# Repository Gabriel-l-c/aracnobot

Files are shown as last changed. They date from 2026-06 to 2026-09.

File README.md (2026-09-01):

# 🕷️ Aracnobot - Estrutura de Tarefas

## ⚡ Eletrônica & Código Embarcado (Hardware & Firmware)
- [ ] **Esquema e Layout (KiCad)**
  - [ ] Desenhar o esquemático elétrico (reguladores de tensão e distribuição de potência).
	- [ ] testar os servos e categorizar os angulos limites (para nunca travar em 0 ou 180, o servo nao
	pode travar!!!).
	- [ ] Testar as baterias, descarga, medir o sinal de alimentação da bateria ( tem picos? ruidos?), 
	para analisar necessidade de circuitos de filtro e proteção.
	- [ ] Circuito de BMS (sistema de gerenciamento de bateria), para controle de carregamento, descarga,
	, protecao contra sobrecarga e subtensao.
  - [ ] Fazer o layout da PCB no KiCad (trilhas largas para os servos e definição das pegadas/capacitores).
  - [ ] Gerar arquivos Gerber para fabricação da placa.
  * problemas:
	O banco de baterias disponivel sao 3s2p litio (3 baterias de litio em seria com 1 em parelelo para cada em serie
ou seja, 6 celulas, 3 pares), a descarga maxima das baterias deve ficar em 1.5C ( para uam bateria de 3Ah de capacidade, 
1.5 C =  4.5A de descarga maxima), cada celula tem 4V2 de tensão maxima e 1.5Ah de descarga. Logo, nao conseguimos
alcançar a potência (carga pesada e motores travados, todos sendo usados de uma vez). Dentro disso, temos que 
montar o firmware afim de nunca ultrapassar o consumo de 4.5A total, nao usar todas as patas de uma vez, carga leve, etc.

  - [ ] Circuito do regulador dos motores. Cuidados e problemas:
  A maior parte de potencia sera consumida pelos motores, logo e onde os reguladores vão trabalhar mais e onde mais energia
  sera transformada em calor. Logo, uma pesquisa de reguladores ideias para a carga de tensão de entrada e corrente de saida
  deve ser feita para iniciar o circuito. Reguladores sugestao: K7805, XL4015.
 
- [ ] **Configuração Inicial do Código**
  - [ ] Configurar ambiente de desenvolvimento (PlatformIO, Arduino IDE ou ESP-IDF).
  - [ ] Mapear os pinos físicos da PCB criada para as definições de variáveis no código.
- [ ] **Cinemática e Movimentação junto a equipe de estrutura**
  - [ ] Implementar algoritmo de Cinemática Inversa (IK) para as pernas.
  - [ ] Desenvolver padrões de marcha (Gait Patterns: tripé, onda, etc.).
  - [ ] Criar funções de estabilização corporal integrando sensor IMU/Giroscópio.
- [ ] **Comunicação, Telemetria & Proteção**
  - [ ] Configurar protocolo sem fio (Wi-Fi, Bluetooth ou ESP-NOW) para controle remoto.
  - [ ] Criar rotina de leitura de nível de bateria e alertas de subtensão para proteger as células LiPo.

## 📐 Estrutura Mecânica Física

## 👁️ Visão Computacional & Percepção

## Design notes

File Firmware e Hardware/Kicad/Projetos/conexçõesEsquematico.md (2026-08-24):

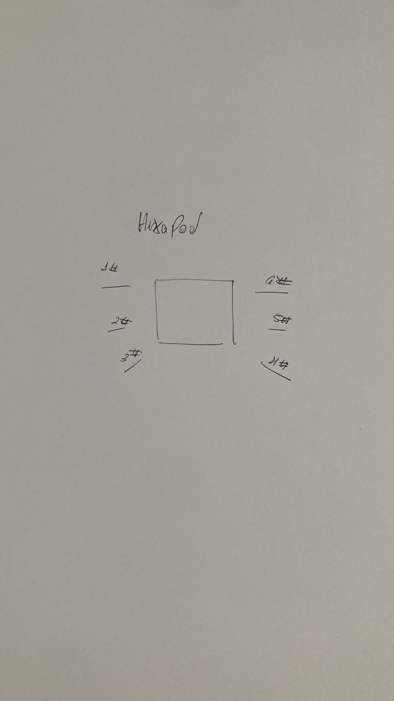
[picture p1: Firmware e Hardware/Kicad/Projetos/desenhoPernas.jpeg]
hexapod pernas


### Tabela de Conexões (Pinos de Sinal PWM)

| Perna | Articulação (Servo) | Pino ESP32 (GPIO) | Observação |
| :--- | :--- | :--- | :--- |
| **Perna 1** | Base (Coxa) | GPIO 33 | |
| | Meio (Fêmur) | GPIO 25 | |
| | Ponta (Tíbia) | GPIO 26 | |
| **Perna 2** | Base (Coxa) | GPIO 27 | |
| | Meio (Fêmur) | GPIO 14 | Pino de boot (Evitar carga pesada na inicialização)|
| | Ponta (Tíbia) | GPIO 12 | Pino de boot (Se o ESP32 não ligar, verifique este servo)|
| **Perna 3** | Base (Coxa) | GPIO 4 | |
| | Meio (Fêmur) | GPIO 32 |  |
| | Ponta (Tíbia) | GPIO 15 |Pino de boot (Emite sinal rápido ao ligar)  |
| **Perna 4** | Base (Coxa) | GPIO 5 | Pino de boot (Pode dar um pequeno tranco ao ligar)|
| | Meio (Fêmur) | GPIO 2 | LED Interno / Dá tranco no boot |
| | Ponta (Tíbia) | GPIO 35| Botão BOOT / Risco de travar o código se puxado para LOW|
| **Perna 5** | Base (Coxa) | GPIO 21 | |
| | Meio (Fêmur) | GPIO 19 | |
| | Ponta (Tíbia) | GPIO 18 | |
| **Perna 6** | Base (Coxa) | GPIO 23 | |
| | Meio (Fêmur) | GPIO 22 | |
| | Ponta (Tíbia) | GPIO 13 | |

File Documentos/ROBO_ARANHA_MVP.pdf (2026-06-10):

Projeto Robô Hexápode para Segurança Pública — MVP v5.0

## PROJETO ROBÔ HEXÁPODE PARA SEGURANÇA PÚBLICA

### MVP 12 Meses — Orçamento Enxuto

Equipe Voluntária | Foco em Componentes Essenciais
Versão: 5.0 | Junho de 2026

### SUMÁRIO

I. Introdução e Definição de MVP

II. Visão Realista

III. Cronograma Executivo (12 Meses)

IV. Divisão de Trabalho e Competências

V. Orçamento Realista

VI. Recursos Gratuitos

VII. Riscos e Mitigação

VIII. Documentação Esperada

IX. Timeline Visual

X. O que a Equipe Vai Aprender

XI. Próximas Ações

XII. Definição de Sucesso em 12 Meses

XIII. Referências de Projetos Hexápodes

### I. INTRODUÇÃO E DEFINIÇÃO DE MVP

O Projeto

O ArachnoBot é uma proposta de Veículo Terrestre Não Tripulado (UGV) com morfologia hexápode, desenvolvido por equipe voluntária com objetivo de demonstrar, em 12 meses, um protótipo funcional capaz de locomover-se em terrenos variados, identificar pessoas por meio de visão computacional e ser operado remotamente via Wi-Fi. O projeto situa-se na interseção de robótica móvel, aprendizado de máquina e sistemas embarcados, com ênfase em baixo custo e tecnologia aberta.

O que é MVP

MVP — Minimum Viable Product, ou Produto Mínimo Viável — é o menor conjunto de funcionalidades que permite validar o conceito central de um projeto com o menor desperdício possível de tempo, dinheiro e esforço. A ideia vem do desenvolvimento de software, mas se aplica diretamente a projetos de hardware e robótica: em vez de tentar construir o robô definitivo de uma vez, constrói-se a versão mais simples que ainda demonstra que o conceito funciona.

No contexto deste projeto, o MVP não é o robô ideal — é o robô mínimo que anda, enxerga e obedece. Qualquer funcionalidade além disso (navegação autônoma completa, mapeamento 3D, comunicação de longo alcance, payload de resgate) pertence a versões futuras. Essa disciplina é essencial para uma equipe voluntária com horas limitadas: sem um escopo mínimo bem definido, o projeto tende a crescer indefinidamente e nunca terminar.

O MVP deste projeto é considerado alcançado quando o robô: locomove-se de forma estável em múltiplos terrenos, transmite vídeo ao vivo para o operador, detecta pessoas com modelo de machine learning embarcado no Raspberry Pi, opera com autonomia mínima de uma hora e pode ser controlado remotamente via Wi-Fi — tudo isso dentro do orçamento de R$ 700 a R$ 920 em componentes novos e em 12 meses de trabalho.

### II. VISÃO REALISTA

Objetivo

Entregar um protótipo funcional de robô hexápode que demonstre: locomoção em terrenos variados, visão computacional com detecção de pessoas, autonomia básica e aprendizado prático em engenharia mecânica, eletrônica e machine learning.

Chassi e Estrutura

O chassi e todas as peças estruturais serão produzidos em impressora 3D Creality K1C com filamento PLA. O projeto não parte do zero: já existem modelos CAD prontos de robôs hexápodes open source como referência base, que serão adaptados conforme as especificidades da equipe. Isso elimina semanas de modelagem do zero e permite focar na integração dos sistemas.

Equipe

Voluntários entre 8 e 12 pessoas trabalhando em horas livres, sem vínculo formal. Todos os integrantes compartilham a responsabilidade de testes e documentação ao longo do projeto — não existe uma pessoa dedicada exclusivamente a essa função.

Orçamento

MVP Mínimo: R$ 700. MVP com sensores básicos: R$ 920. A equipe já possui: Raspberry Pi 4B, câmera RPi v2, bateria Li-Po 11.1V, ESP32 e filamento PLA — totalizando aproximadamente R$ 880 em componentes disponíveis.

Tempo por Pessoa

Aproximadamente 8 a 12 horas semanais por integrante, compatível com rotina de trabalho ou estudo.

### III. CRONOGRAMA EXECUTIVO (12 MESES)

T1 — Meses 1 a 3: Design e Prototipagem

- Mês 1: Adaptação do modelo CAD de referência para a K1C, definição de encaixes e tolerâncias de impressão
- Mês 2: Compra dos componentes (R$ 700), início das impressões, montagem dos servomotores MG90 na primeira perna
- Mês 3: Uma perna funcional com controle de servos validado

T2 — Meses 4 a 6: Integração e Locomoção

- Mês 4: Seis pernas montadas e controladas pelo firmware base
- Mês 5: Algoritmos de marcha (tripod gait) implementados e testados em campo
- Mês 6: Câmera integrada com stream de vídeo ao vivo, pipeline de detecção de pessoas ativo

T3 — Meses 7 a 9: Machine Learning e Autonomia

- Mês 7: Coleta do dataset (500+ imagens), treinamento inicial no Google Colab
- Mês 8: Modelo ML integrado ao Raspberry Pi, inferência em tempo real
- Mês 9: Autonomia básica funcionando — robô reage a detecção sem intervenção do operador

T4 — Meses 10 a 12: Testes, Polimento e Documentação

- Mês 10: Testes em campo com diferentes terrenos e condições de luz
- Mês 11: Correções, otimização de consumo de bateria, polimento geral
- Mês 12: Documentação final, vídeo de demonstração, relatório de lições aprendidas

### IV. DIVISÃO DE TRABALHO E COMPETÊNCIAS

A tabela abaixo apresenta as funções, quantidade de integrantes e carga horária semanal estimada. Testes e documentação são responsabilidade compartilhada de toda a equipe — não existe função dedicada para isso.

Função | Qtd | Horas/semana | Área Principal
Lead Mecânico | 1 | 10h | Engenharia Mecânica
Mecânico | 1 | 8h | Engenharia Mecânica
Lead Eletrônico | 1 | 10h | Engenharia Elétrica
Firmware Lead | 2 | 12h | Sistemas Embarcados / Integração
Firmware Dev | 1 | 8h | Sistemas Embarcados
ML Engineer | 1 | 10h | Machine Learning
Visão Computacional | 1 | 8h | Computer Vision

Tabela 1 — Composição da equipe e carga horária

Lead Mecânico

O Lead Mecânico é o responsável central pelo projeto estrutural do robô. Adapta os modelos CAD de referência para a impressora K1C, define tolerâncias de encaixe considerando as características do PLA e as dimensões dos servomotores MG90, revisa e aprova cada peça antes da impressão, decide estratégias de reforço estrutural nas regiões de maior esforço mecânico (juntas de quadril e fêmur), e resolve problemas de montagem que exijam redesenho. É o ponto final de decisão para qualquer questão de estrutura física.

Mecânico (1 pessoa)

Com modelos CAD de referência prontos e a K1C disponível, uma única pessoa de bancada é suficiente para este escopo. O Mecânico opera a K1C para impressão das peças, realiza o pós-processamento (remoção de suportes, lixamento de encaixes), monta as pernas e o chassi, aperta os parafusos nos torques corretos para não comprimir o PLA, e testa a amplitude de movimento de cada articulação antes de passar para a eletrônica. Todo problema que exija redesenho vai de volta ao Lead Mecânico.

Lead Eletrônico

O Lead Eletrônico é responsável por todo o projeto de circuito do robô: projetar o esquema elétrico completo da distribuição de energia (bateria Li-Po 11.1V → BEC 5V/3A → servos e ESP32), definir a topologia de conexão dos 18 servomotores MG90 evitando sobrecarga de corrente em qualquer ponto, projetar ou montar a PCB, escolher e validar conectores XT60 e JST, e garantir que nenhum componente opere fora da faixa segura de tensão ou corrente. É o responsável final por qualquer decisão de circuito e pela segurança elétrica do sistema.

Firmware Lead (2 pessoas)

Dada a ausência de especialistas em controle e na integração dos nós do projeto, a função é ocupada por duas pessoas com divisão interna clara. O primeiro Firmware Lead cuida da arquitetura de software embarcado e controle: define como o ESP32 gera sinais PWM para os 18 servos em paralelo sem conflito de threads, estabelece o protocolo de comunicação serial/I2C entre ESP32 e Raspberry Pi, escreve o código de controle de marcha em C (tripod gait) e integra o driver do IMU MPU6050. O segundo Firmware Lead cuida da infraestrutura de integração e DevOps: configura e mantém o servidor de CI (container Docker rodando no próprio Raspberry Pi ou em servidor externo), gerencia o repositório GitHub com branches protegidas e pipelines de CI/CD, estabelece a comunicação de telemetria Wi-Fi (protocolo, autenticação e stream de dados), e garante que os módulos de ML e visão computacional se integrem corretamente ao sistema operacional do Pi. Ambos compartilham o debugging de integração entre áreas.

Firmware Dev

O Firmware Dev implementa funcionalidades dentro da arquitetura definida pelos dois Firmware Leads — sem responsabilidade de decisão de arquitetura ou DevOps. Na prática: escreve as rotinas de PWM, o driver de comunicação I2C com o IMU MPU6050, o protocolo de recebimento de comandos via Wi-Fi e os loops de controle dos servos. A diferença central em relação aos Leads é que o Dev executa dentro das regras que os Leads estabeleceram, e reporta a eles quando encontra limitações de arquitetura que precisam ser revisadas.

ML Engineer

O ML Engineer é responsável por todo o pipeline de aprendizado de máquina: define a estratégia de coleta do dataset (ambientes, iluminação, ângulos), organiza e anota as imagens (mínimo 500), escolhe a arquitetura de rede neural mais leve para inferência no Raspberry Pi (MobileNet, YOLOv5n ou similar), treina o modelo no Google Colab com transfer learning a partir de pesos pré-treinados, exporta o modelo em formato compatível com o Pi (TensorFlow Lite ou ONNX), e retreina quando o modelo não generalizar bem para novos ambientes.

Visão Computacional

A Visão Computacional integra o modelo do ML Engineer com a câmera RPi v2 em tempo real: escreve o pipeline de captura de frames com OpenCV, passa cada frame pelo modelo de detecção e extrai bounding boxes com confiança mínima configurável, implementa tracking para manter o ID de cada pessoa detectada entre frames, transforma as saídas de detecção em sinais de controle que o firmware usa (ex.: pessoa à esquerda → virar esquerda), e otimiza o pipeline para atingir taxa mínima de 10 FPS no Pi sem travar o sistema.

Testes e Documentação — Responsabilidade Compartilhada

Não existe uma pessoa dedicada a testes e documentação. Cada integrante documenta o que produz: o Lead Mecânico entrega os arquivos STL e CAD final; o Lead Eletrônico entrega o esquema elétrico e BOM com links; os Firmware Leads mantêm o README técnico e o histórico do repositório GitHub; o ML Engineer documenta o processo de treinamento e métricas; e a Visão Computacional registra os parâmetros do pipeline. Nos meses 10 a 12 toda a equipe contribui para o vídeo final, o relatório de lições aprendidas e o guia de montagem.

### V. ORÇAMENTO REALISTA

Opção 1: MVP Mínimo — R$ 700

Item | Qtd | R$
Servomotores MG90 | 18 | 324
Alumínio (barras 20x20, 1m total) | — | 120
Parafusos, porcas, rolamentos (kit) | — | 100
Fios, conectores, garras servo | — | 80
PCB (perftape ou fenolite) | — | 40
BEC 5V/3A | — | 30
Conectores XT60, JST (kit) | — | 6
TOTAL | — | 700

Tabela 2 — Componentes MVP mínimo

Opção 2: MVP com Sensores Básicos — R$ 920

Item | Qtd | R$
Opção 1 (base) | — | 700
Sensor Ultrassom HC-SR04 | 4 | 120
IMU MPU6050 | 1 | 40
Extras (LEDs, buzzer, fita) | — | 60
TOTAL | — | 920

Tabela 3 — Componentes MVP com sensores

Componentes Já Disponíveis na Equipe

Item | Valor estimado (R$)
Raspberry Pi 4B | 350
Câmera RPi v2 | 150

Item | Valor estimado (R$)
Bateria Li-Po 11.1V | 150
ESP32 | 80
Filamento PLA (K1C) | 150
Impressora K1C | já disponível
SUBTOTAL disponível | ~R$ 880

Tabela 4 — Componentes disponíveis

Total geral do projeto considerando componentes novos mais os já disponíveis: entre R$ 1.580 e R$ 1.800.

### VI. RECURSOS GRATUITOS

Recurso | Plataforma | Custo
CAD | Fusion 360 (licença educação) | Grátis
Impressão 3D | K1C (já disponível) | Grátis
GPU para ML | Google Colab | Grátis (15h/mês)
Repositório e CI | GitHub + GitHub Actions | Grátis
Containers | Docker (no próprio Pi) | Grátis
Comunicação | Discord / Telegram | Grátis
Documentação | Google Docs / Notion | Grátis
Dev Tools | VS Code, Python, TensorFlow | Grátis (open source)

Tabela 5 — Recursos disponíveis sem custo

### VII. RISCOS E MITIGAÇÃO

Servo MG90 fraco

Testar 2 a 3 unidades antes de comprar as 18. Se insuficiente, usar redução mecânica impressa em PLA ou migrar para MG996R no eixo de quadril.

Peça impressa quebrando

Imprimir com 40% de preenchimento mínimo e pelo menos 3 paredes. Manter STLs versionados no GitHub para reimprimir qualquer peça rapidamente.

Cinemática não convergindo

Testar primeiro em simulação (CAD animado). Se não funcionar, usar 2 graus de liberdade por perna no lugar de 3.

Bateria descarregando rápido

Normal com 18 servos em carga. Objetivo de autonomia: 1 a 2 horas. Monitorar consumo com medidor de corrente e identificar servos que travam.

ML não generalizando

Coletar mais dados com variação de iluminação e ângulo. Retreinar no Colab. Usar data augmentation para ampliar o dataset sem coletar mais imagens.

Integração entre módulos falhando

Os dois Firmware Leads são responsáveis por integração. Estabelecer interfaces definidas entre módulos antes de começar — ninguém começa sem documentar a interface que vai exportar.

Docker ou servidor de CI caindo

O Raspberry Pi do próprio robô pode hospedar o servidor de integração em container. Se o Pi estiver em campo, usar GitHub Actions como fallback de CI.

Equipe desistindo

Equipe de 8 pessoas reduz o risco de paralisia por saída de um integrante. Documentação clara no GitHub garante que o substituto consiga continuar sem depender de transferência de conhecimento verbal.

Demora no AliExpress

Comprar os componentes 1 a 2 meses antes do início da montagem. Peças pequenas (parafusos, conectores) comprar em loja local como backup.

### VIII. DOCUMENTAÇÃO ESPERADA (MÊS 12)

### 1. Robô Funcional

- Protótipo v1.0 construído, testado e demonstrável publicamente
- Anda em múltiplos terrenos (concreto, grama, terreno irregular leve)
- Detecta pessoas com ML em tempo real
- Autonomia mínima de 1 hora

### 2. Código Fonte (GitHub)

- Firmware em Python e C, mínimo 3.000 linhas de código
- Modelos ML exportados em TensorFlow Lite ou ONNX
- Dataset anotado com mínimo de 500 imagens
- README claro com instruções de build, flash e operação
- Dockerfile para o ambiente de integração

### 3. Documentação Técnica

- Guia de montagem passo a passo com fotos
- Arquivos CAD (Fusion 360) e STLs prontos para impressão na K1C
- Bill of Materials (BOM) com links e preços atualizados
- Esquema elétrico completo
- Guia de operação do robô

### 4. Mídia

- Vídeos de testes em campo
- Vídeo final de demonstração (3 a 5 minutos)
- Fotos do processo de construção
- Slides para apresentação

### 5. Relatório Final

- O que funcionou e por quê
- O que não funcionou e por quê
- Lições aprendidas por área
- Roadmap para a versão 2.0

### IX. TIMELINE VISUAL

Período | Marcos
Meses 1–3 | CAD adaptado | Componentes comprados | 1 perna funcional
Meses 4–6 | 6 pernas montadas | Algoritmos de marcha | Câmera + detecção
Meses 7–9 | Dataset + treinamento | ML no robô | Autonomia básica
Meses 10–12 | Testes em campo | Polimento | Documentação final

Tabela 6 — Timeline executivo

### X. O QUE A EQUIPE VAI APRENDER

Área | Conteúdo
Mecânica | Cinemática, dinâmica de hexápodes, impressão 3D com K1C, tolerâncias de PLA
Eletrônica | PCB design, distribuição de potência, seleção de componentes
Firmware | C embarcado, PWM, I2C, threads, protocolos de comunicação serial e Wi-Fi
Integração / DevOps | Docker, GitHub Actions, CI/CD, integração hardware-software, debugging de sistema
Machine Learning | Transfer learning, dataset curation, treinamento no Colab, exportação de modelos
Visão Computacional | OpenCV, CNN, detecção de objetos, tracking, pipeline em tempo real

Tabela 7 — Aprendizados por área

### XI. PRÓXIMAS AÇÕES

Esta semana

- Reunir a equipe e confirmar os integrantes de cada função
- Definir responsabilidades individuais e os dois Firmware Leads
- Montar cronograma compartilhado no GitHub Projects ou Notion
- Pesquisar e selecionar o modelo CAD de referência para adaptação

Próximas 2 semanas

- Iniciar adaptação do CAD no Fusion 360
- Fechar lista de compra (BOM) e realizar o pedido dos componentes
- Criar o repositório GitHub com estrutura de branches, README inicial e Dockerfile base
- Configurar o ambiente Docker no Raspberry Pi

Mês 1

- CAD da primeira perna finalizado e aprovado pelo Lead Mecânico
- Componentes recebidos e conferidos
- Primeira perna impressa na K1C e montada

### XII. DEFINIÇÃO DE SUCESSO EM 12 MESES

O projeto será considerado bem-sucedido quando entregar um protótipo funcional que atenda aos seguintes critérios:

- Anda em múltiplos terrenos de forma estável
- Transmite vídeo ao vivo para o operador
- Detecta pessoas com ML embarcado no Raspberry Pi
- Opera com autonomia mínima de 1 hora
- Pode ser controlado remotamente via Wi-Fi
- Está completamente documentado no GitHub
- Pronto para demonstração pública
- Serve como base sólida para a versão 2.0

Custo em componentes novos: R$ 700 a R$ 920

Tempo total: 12 meses com 8 a 12 horas semanais por pessoa

Equipe: 8 voluntários

Impacto: portfólio técnico relevante para currículo e GitHub de todos os integrantes

### XIII. REFERÊNCIAS DE PROJETOS HEXÁPODES

Os repositórios abaixo servem como referência de arquitetura, código e documentação. Os modelos CAD e algoritmos devem ser adaptados e não copiados diretamente. Dar crédito quando utilizar código ou estruturas de terceiros.

Repositório | Relevância
mithi/hexapod | Cinemática inversa e simulação visual — base matemática do movimento
MakeYourPet/hexapod | Design mecânico acessível e controle de servos — referência de montagem
rookidroid/hexapod | Implementação embarcada de baixo custo — referência de firmware
SmallpTsai/7688-hexapod | Integração com IoT e comunicação Wi-Fi — referência de telemetria
neuroprod/InsectRobotSimulatio n | Simulação de locomoção bioinspirada — validação de algoritmos
ByteRyze/Hexapod_2 | Referência de hardware e estrutura física — tolerâncias e encaixes
ClimbSnail/HexapodRobot_STC 15 | Firmware em microcontrolador de baixo custo — referência de C embarcado
JakobLeander/hexapod | Planejamento de trajetória e controle de marcha — algoritmos de gait

Tabela 8 — Repositórios de referência

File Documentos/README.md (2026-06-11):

# ArachnoBot — Proposta de UGV para Suporte em Ambientes Hostis e Primeiros Socorros

> *"Os cientistas estudam o mundo como ele é; os engenheiros criam o mundo que nunca existiu."*
> — Theodore von Kármán

---

## Sobre o Projeto

O **ArachnoBot** é uma proposta de **Veículo Terrestre Não Tripulado (UGV)** com morfologia hexápode. 

Ele foi pensado a partir do cenário de uso atual de drones pela polícia da Grande Vitória. Com isso, uma ideia veio à mente: quais limitações os drones deles têm e como seria possível suprir essas limitações? 

Como a parte de ações policiais possui conflitos éticos e de violência, optou-se pela área de primeiros socorros, que tem o mesmo apelo de necessidade de tecnologia, porém ainda não conta, por exemplo, com drones dedicados a isso. 

Logo, ele foi concebido para atuar como ferramenta de apoio em operações de primeiros socorros, especialmente em locais onde a presença humana direta representa risco severo ou é temporariamente inviável.

O projeto se situa na interseção de três domínios:

- **Robótica Móvel de Resgate** — navegação e teleoperação em terrenos adversos
- **Atendimento Pré-Hospitalar (APH)** — entrega de suprimentos médicos essenciais a vítimas isoladas
- **Engenharia de Sistemas Embarcados** — plataforma de baixo custo e arquitetura aberta

### Areas Que São Trabalhadas :

* **Sistemas Embarcados:** Programação e arquitetura de computação embarcada de tempo real (utilizando microcontroladores e microprocessadores). Foca-se no desenvolvimento do firmware de controlo central, gestão de interrupções, temporização e geração de sinais PWM (Pulse Width Modulation) coordenados para o acionamento síncrono dos 18 servomotores do robô.
* **Redes de Comunicação e IoT:** Implementação de arquiteturas de rede sem fios (Wi-Fi e Radiofrequência) de baixa latência e alta resiliência para teleoperação em ambientes confinados. Inclui a especificação de protocolos de comunicação leves (como MQTT para telemetria estruturada e fluxos UDP) destinados ao envio de dados de sensores e à transmissão contínua (*streaming*) de vídeo em tempo real.
* **Robótica Móvel e Cinemática:** Estudo de modelos matemáticos de cinemática inversa aplicados a geometrias bioinspiradas, planeamento de trajetórias de marcha (gait planning) para terrenos irregulares, e controlo em malha fechada utilizando dados de giroscópios e acelerómetros para a estabilização postural.
* **Visão Computacional e Inteligência Artificial:** Integração de algoritmos de processamento digital de imagem e modelos otimizados de redes neuronais artificiais para a deteção automatizada de pessoas. O foco está na identificação de vítimas em cenários de visibilidade degradada por fumo, poeira ou baixa luminosidade.
* **Eletrónica de Potência e Gestão Energética:** Desenho de circuitos de filtragem de ruído eletromagnético provocado pelos motores, dimensionamento de sistemas de regulação de tensão de alta corrente (circuitos BEC) e monitorização inteligente do ciclo de descarga das baterias para garantir a integridade dos componentes lógicos e de processamento.

### Objetivos :
* Movimentaçaõ: robo que consiga se locomover de forma "limpa", e se adaptar a perda de 1 perna caso algum motor quebre, simulacao em 3d do robo para apurar resultado e obter dados
* Energia: Autonomia de 30min a 1h, placa personalizada  
* Visão: identificacao de obstaculos, pessoas, tudo que envolva acidente etc.
* Machine learning: algorithmo para auxiliar quem ira pilotar o robo a tomar decisoes voltadas a primeiros socorros
* Firware : estrutura de sensores e comunicação com microcontrolador eficiente.

> Este repositório documenta a **proposta, fundamentação teórica e planejamento** do projeto. O desenvolvimento do protótipo físico está em fase de iniciação.
> Apartir daqui e mais teórico : )

---

## O Problema: A Lacuna na Hora de Ouro

Em operações de Busca e Salvamento (SAR — *Search and Rescue*) e em intervenções em desastres — incêndios urbanos, colapsos estruturais, ocorrências de segurança pública — existe uma janela temporal crítica denominada **"hora de ouro do trauma"**. Neste intervalo, intervenções simples de primeiros socorros como controle de hemorragia, abertura de vias aéreas e prevenção de hipotermia são determinantes para a sobrevivência.

As equipes de resgate humano são frequentemente **impedidas de acessar as vítimas** neste período por fatores como:

| Barreira | Exemplos |
|---|---|
| Instabilidade estrutural | Edifícios colapsados, escombros |
| Altas temperaturas | Incêndios urbanos, focos industriais |
| Zonas de exclusão tática | Protocolos de segurança em operações policiais e de defesa civil |
| Topografia adversa | Morros, becos, escadarias, regiões alagadas |

> *"Mais de 50% dos civis feridos durante combates em centros urbanos precisam apenas receber os primeiros socorros — acrescidos de um simples antibiótico oral e um analgésico. Eles precisam apenas de cuidados imediatos e de um tratamento complementar de estabilização, e não ser hospitalizados."*
> — CICV, *Primeiros Socorros em Conflitos Armados e Outras Situações de Violência*, 2006 (ICRC 007/0870)

O ArachnoBot propõe-se a preencher esta lacuna logística e temporal, projetando a capacidade de assistência do socorrista para dentro das zonas de exclusão antes ou durante o acesso humano.

---

## Objetivos

### Geral

Desenvolver a proposta e, futuramente, um protótipo funcional de UGV hexápode voltado para **reconhecimento de terreno** e **entrega remota de suprimentos de primeiros socorros** em ambientes de difícil ou impossível acesso humano imediato.

### Específicos

- Definir os requisitos mecânicos de uma plataforma hexápode capaz de transpor obstáculos urbanos típicos (escombros, degraus, terrenos irregulares)
- Especificar a arquitetura de sensoriamento e telemetria (câmera, temperatura, IMU) para transmissão de dados em tempo real ao operador
- Projetar um compartimento de carga adaptado ao transporte de suprimentos essenciais de APH
- Elaborar a arquitetura de software para teleoperação e, em estágios futuros, navegação semiautônoma
- Mapear protocolos de uso alinhados às diretrizes internacionais do CICV para primeiros socorros em ambientes hostis
- Validar a proposta com foco em baixo custo de produção e potencial de escalabilidade

---

## Fundamentação Teórica e Estado da Arte

### Robótica Autônoma em Suporte a Bombeiros

A inserção de UGVs para suporte a bombeiros em ambientes fechados já é uma realidade validada pela literatura. **Talavera et al. (2023)** demonstraram, no *Journal of Field Robotics*, a eficácia de arquiteturas autônomas para auxiliar intervenções em locais com risco de colapso estrutural — realizando reconhecimento térmico e visual que os Equipamentos de Proteção Individual (EPIs) humanos não toleram por tempo suficiente. O estudo sustenta diretamente a premissa central deste projeto: robôs terrestres podem ser a vanguarda segura de uma operação de resgate.

### Consciência Situacional e Mapeamento em Catástrofes

Em situações de desastre, a telemetria é vital. O consórcio europeu **TRADR** demonstrou que drones terrestres com sensores a laser geram mapeamento 3D de zonas sinistradas em tempo real, fornecendo aos comandantes dados críticos antes de expor as equipes ao perigo. Esta capacidade de observar sem estar presente é um dos pilares funcionais do ArachnoBot.

### APH Tático e Entrega Logística de Resgate

O desenvolvimento de robôs focados especificamente no transporte logístico de emergência — como os documentados no projeto **FireBot** (capaz de suportar temperaturas acima de 530°C, conforme CNN Portugal) — evidencia a demanda global por sistemas mecânicos de entrega em zonas hostis. O ArachnoBot incorpora este conceito adaptado ao contexto do APH: o robô não trata a vítima, mas **entrega os meios para que ela possa receber ou aplicar os primeiros socorros** sob orientação remota de um profissional.

### Protocolos Humanitários e APH em Campo

O CICV, no manual *Primeiros Socorros em Conflitos Armados e Outras Situações de Violência* (ICRC 007/0870, 2006), estabelece que a abordagem primária de uma vítima segue a sequência **A-B-C-D-E** — Vias aéreas, Respiração, Circulação, Incapacidade e Exposição. Os suprimentos transportados pelo ArachnoBot são selecionados para atender exatamente estas etapas críticas, com ênfase no controle de hemorragia (C) e na proteção contra hipotermia (E).

O **Manual de Medidas de Segurança e Primeiros Socorros** (Chang, 2015) complementa esta base com a especificação dos materiais essenciais de uma caixa de primeiros socorros de campo e os procedimentos de atendimento inicial, sendo referência direta para a definição da carga útil do robô.

### Morfologia Hexápode para Terrenos Adversos

A escolha de seis pernas é funcional, não estética. Plataformas hexápodes apresentam **redundância de locomoção** — a falha de uma perna não paralisa o sistema —, maior estabilidade estática em terrenos irregulares e capacidade de transpor obstáculos que inviabilizam plataformas rodadas. A comunidade open-source já documentou extensamente soluções de referência que fundamentarão a arquitetura mecânica deste projeto.

---

## Conceito de Operação

```
  OPERADOR / SOCORRISTA
  (zona segura)
        |
        |  Teleoperação via Wi-Fi / RF
        |  Vídeo ao vivo + telemetria
        v
  +-------------------------+
  |      ARACHNOBOT UGV     |
  |  Câmera FPV             |
  |  Sensores de telemetria |
  |  Compartimento de carga |
  |  6 pernas / servomotores|
  +-------------------------+
        |
        |  Navega pelo ambiente hostil
        v
  +-------------------------+
  |      VITIMA ISOLADA     |
  |  Recebe suprimentos     |
  |  Orientada remotamente  |
  |  pelo socorrista        |
  +-------------------------+
```

O operador, em segurança, visualiza o ambiente por meio da câmera do robô, navega até a vítima e libera os suprimentos de APH. Se a vítima estiver consciente, o socorrista pode orientá-la, ou alguém próximo,  remotamente por áudio sobre como aplicar torniquete, curativo compressivo ou cobertor térmico — seguindo os protocolos A-B-C-D-E do CICV — até a chegada da equipe de resgate ao local.

---

## Carga Útil Prevista — Kit de APH

Os suprimentos são selecionados com base nas intervenções de maior impacto na hora de ouro, conforme os protocolos do CICV (2006) e do Manual Chang (2015):

| Suprimento | Finalidade | Referência |
|---|---|---|
| Torniquete (CAT ou improviso) | Controle de hemorragia em membros | CICV Sec. 6.1.3 / Chang 14.1 |
| Bandagem de compressão | Curativo compressivo em ferimentos | CICV Sec. 6.2.6 / Chang 14.1 |
| Máscara de ressuscitação | Ventilação artificial boca-a-máscara | CICV Sec. 6.1.2 / Chang 4.2.1 |
| Curativos estéreis (P/M/G) | Cobertura de ferimentos abertos | Chang 2.2 / CICV Sec. 6.2.6 |
| Gaze + agente hemostático | Controle de sangramento profuso | CICV Sec. 6.1.3 / Chang 14.1 |
| Soro fisiológico (sachê) | Limpeza de ferimentos | Chang 2.2 e 3.3.1 |
| Cobertor térmico aluminizado | Prevenção de hipotermia e choque | CICV Sec. 6.1.5 / Chang 10 |

**Nota operacional:** O robô realiza exclusivamente a entrega de suprimentos e a transmissão de vídeo e áudio. A administração dos primeiros socorros é responsabilidade da vítima consciente orientada remotamente, ou das equipes que chegam subsequentemente.

---

## Roadmap

| Fase | Descrição | Status |
|---|---|---|
| Fase 0 | Proposta conceitual e levantamento bibliográfico | Em andamento |
| Fase 1 | Especificação de requisitos e seleção de componentes |Não iniciado |
| Fase 2 | Projeto mecânico (CAD) e simulação de cinemática | Não iniciado |
| Fase 3 | Prototipagem da plataforma de locomoção | Não iniciado  |
| Fase 4 | Integração de sensores e sistema de comunicação | Não iniciado  |
| Fase 5 | Desenvolvimento da interface de teleoperação | Não iniciado  |
| Fase 6 | Testes integrados e validação do protótipo | Não iniciado  |

---

## Repositórios de Referência — Plataformas Hexápode Open Source

| Repositório | Relevância |
|---|---|
| [mithi/hexapod](https://github.com/mithi/hexapod) | Cinemática inversa e simulação visual |
| [MakeYourPet/hexapod](https://github.com/MakeYourPet/hexapod) | Design mecânico acessível e controle de servos |
| [rookidroid/hexapod](https://github.com/rookidroid/hexapod) | Implementação embarcada de baixo custo |
| [SmallpTsai/7688-hexapod](https://github.com/SmallpTsai/7688-hexapod) | Integração com plataformas IoT e comunicação |
| [neuroprod/InsectRobotSimulation](https://github.com/neuroprod/InsectRobotSimulation) | Simulação de locomoção bioinspirada |
| [ByteRyze/Hexapod_2](https://github.com/ByteRyze/Hexapod_2) | Referência de hardware e estrutura física |
| [ClimbSnail/HexapodRobot_STC15](https://github.com/ClimbSnail/HexapodRobot_STC15) | Firmware em microcontrolador de baixo custo |
| [JakobLeander/hexapod](https://github.com/JakobLeander/hexapod) | Planejamento de trajetória e controle de marcha |

---

## Referências Bibliográficas e Documentais

CHANG, Yen-Li Chain. **Manual de Medidas de Segurança e Procedimento de Primeiros Socorros no Acampamento Escoteiro**. Projeto da Insígnia de Madeira — Curso Avançado Ramo Escoteiro, GENSM 49-PR. 2015.

CNN PORTUGAL. **Estudantes constroem robot que consegue aguentar temperaturas acima dos 530 graus**. Projeto FireBot. [S. l.], [s. d.].

COMITÊ INTERNACIONAL DA CRUZ VERMELHA (CICV). **Primeiros Socorros em Conflitos Armados e Outras Situações de Violência**. n. ICRC 007/0870. Genebra, Suíça: CICV, 2006.

DESENVOLVIMENTO de Robôs de Resgate. *Documentação Técnica de Referência.* [S. l.: s. n., s. d.].

EURONEWS. **Os robôs que ajudam os bombeiros italianos**. Projeto TRADR — Consórcio Europeu de Robótica de Resgate. [S. l.], [s. d.].

PEOPLE.CN. **Inovações em Robôs de Resgate e Transporte de Emergência**. [S. l.], [s. d.].

SAFE Search and Rescue Operations Based on Autonomous Robots: A Systematic Review of the General System Architecture. *Revisão Sistemática de Literatura em Robótica SAR.* [S. l.: s. n., s. d.].

TALAVERA et al. An autonomous ground robot to support firefighters interventions in indoor environments. **Journal of Field Robotics**, 2023.

---

## Contexto Acadêmico

Este projeto é concebido no âmbito universitário com caráter multidisciplinar, reunindo as seguintes áreas:

- **Engenharia Mecânica** — Projeto estrutural e cinemática da plataforma hexápode
- **Engenharia Elétrica / Eletrônica** — Sistemas embarcados, sensoriamento e gerenciamento de energia
- **Ciência da Computação** — Comunicação, visão computacional e interface de controle
- **Saúde / APH** — Definição dos protocolos de primeiros socorros e especificação da carga útil

---

*"Prestar os primeiros socorros não significa somente fazer respiração artificial ou colocar um curativo num ferimento. Significa também pegar na mão de alguém que está ferido, tranquilizar os que estão assustados ou em pânico, dar um pouco de si."*
— CICV, 2006

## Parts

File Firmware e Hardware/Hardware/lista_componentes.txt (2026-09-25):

Reguladores:

L7805  - 10x

Rasberrypi:
4 model b
3 model b+

Esp:

Esp32devkit u-v4
Esp32 dev kit v1
nanoEsp32-c6 v1.0 v1711

Mosfet :
IRFZ44N - 10x

Diodo:
zener:
3V0, 3V3, 3V6, 4V7, 5V1, 5V6, 6V2, 10V, 12V, 13V, 15V, 18V, 27V, 30V

BMS:
2s 15w 1,5A  - v1342
2s 10A - v813

Switch: 
SS12D00
KCD1
Connector:
deans tipo t
jst-rcy

baterias: 
3 packs de 2P - 3V7 4000mAh

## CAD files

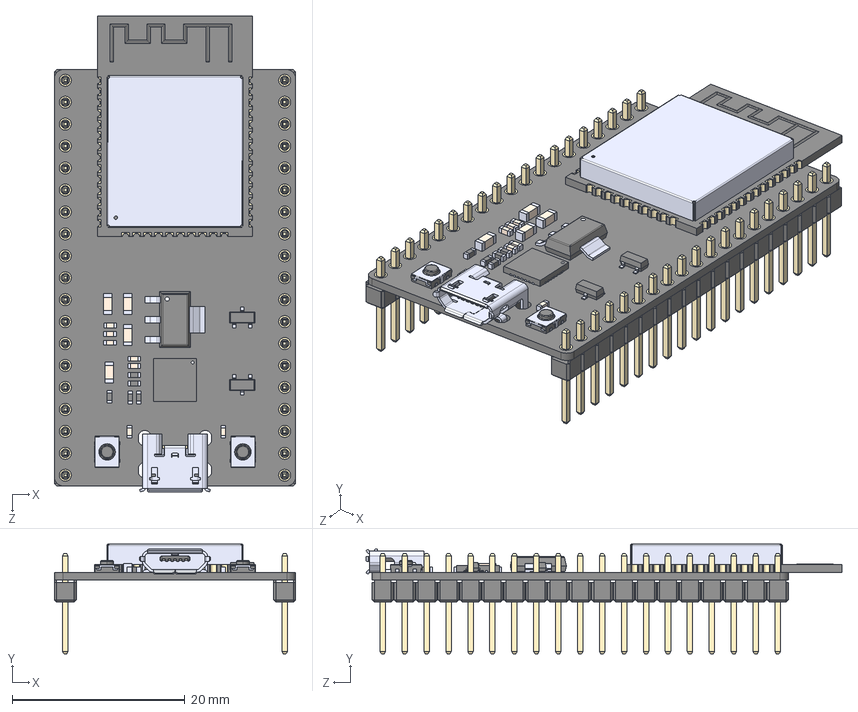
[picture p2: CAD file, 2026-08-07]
Firmware e Hardware/Kicad/Biblioteca/DEVKIT_V1_ESP32-WROOM-32/DEVKIT_V1_ESP32-WROOM-32.step
27.9 x 12.7 x 55.1 mm
board
header x 2
ESP32-WROOM-32D
micro usb
button x 2
CP2102N-A01-GQFN28
AMS1117-3.3
SS8050-G
components^DEVKIT V1 ESP32-WROOM-32

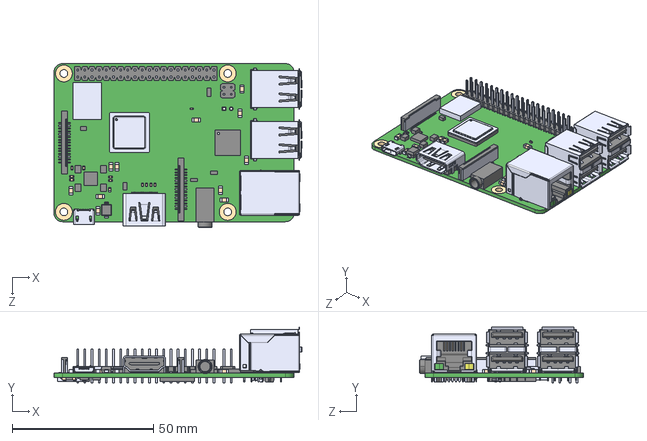
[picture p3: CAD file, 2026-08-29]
Firmware e Hardware/Kicad/Biblioteca/RASPBERRY_PI_3_MODEL_B_/RASPBERRY_PI_3_MODEL_B_.step
87.8 x 19.8 x 58.0 mm

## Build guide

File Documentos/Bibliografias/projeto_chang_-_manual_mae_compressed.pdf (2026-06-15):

PROJETO DA INSÍGNIA DE MADEIRA

## MANUAL DE MEDIDAS DE SEGURANÇA E

## PROCEDIMENTO DE PRIMEIROS SOCORROS

## NO ACAMPAMENTO ESCOTEIRO

PROJETO DE CONCLUSÃO DO CURSO AVANÇADO RAMO ESCOTEIRO 2015

CHANG YEN-LI CHAIN

CHEFE TROPA III DO GENSM - 49-PR

SUMÁRIO:

3.3. Avaliação Secundária (cuidado de ferimentos, fraturas e preparo para remoção) .....20

PREFÁCIO

Sou pediatra de formação e entrei no movimento escoteiro por causa dos meus 3 filhos, que foram escoteiros do Grupo Escoteiro Nossa Senhora Medianeira (GENSM 49-PR), há 24 anos atrás. Comecei primeira como mãe de apoio, depois como médica voluntária, e há mais de 10 anos sou chefe assistente na Tropa escoteira, e atualmente chefe da tropa III. Já participei de 3 Jamborees Internacionais (da Inglaterra, da Suécia e do Japão), 5 Jamborees Nacionais, 2 Jamborees Pan-americanos (México e Equador) e 2 ARP,4 Acanjesus (acampamentos dos grupos escoteiros do colégio Jesuítas), além dos diversos acampamentos do nosso grupo escoteiro e de outros também. Maioria das vezes trabalhei como médica.

Observei que muitos atendimentos médicos poderiam ser evitados se todos seguissem as recomendações e ensinamentos propostos pela UEB. Entretanto, o movimento escoteiro tem muita rotatividade, tanto de chefes como de escoteiros, e por isso é necessário que se lembrem sempre as recomendações de medidas de segurança e treinamento de primeiros socorros.

Este manual serve para a consulta de chefes e escoteiros a fim de organizarem seus acampamentos com segurança, prevenindo desta forma acidentes, e auxiliando-os a saberem aplicar os primeiros socorros nas situações que exigem ação.

E também ajuda osescoteiros para tirar a especialidade de primeiros socorros.

Os anexos podem parecer um pouco antigos, pois na atualidade tudo pode ser tirado do SIGUE que agora é PAXTUR. Tanta atualização do desenvolvimento e progressão das jovens, ficha médica, como autorização para a atividade. Mas são lembranças que precisam de todos esses documentos e informações para ter uma atividade escoteira com segurança.

Agradecimentos:

Ao meu assessor pessoal Nelson W. Hey.Juior.

E minhas filhas: Milena e Amanda Chang Chain que tiveram paciência e disposição para correção e digitação desse manual.

CHANG YEN-LI CHAIN

### 1. PADRÃO DE ATIVIDADE ESCOTEIRA

## O sucesso do acampamento está relacionado à:

Programação + Nutrição + Saúde + Segurança.

1.1.Antes

a) Estabelecer os objetivos de desenvolvimento que se pretende alcançar.
b) Avaliar os recursos humanos.
c) Avaliar recursos materiais.
d) Planejamento.
e) Visitar o local.
f) Reconhecimento do terreno.
g) Realização de percurso.
h) Programação.
i) Transporte.
j) Autorização.

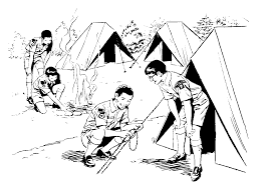
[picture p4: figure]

a) Estabelecer os objetivos.Uma atividade escoteira não é meramente uma recreação. Cada tipo de atividade enfatizará atributos das diversas áreas de desenvolvimentocomo: a aplicação de determinados conhecimentos e técnicas; a exigência de certas capacidades físicas e destrezas; e a construção e/ou consolidação de comportamentos e atitudes desejáveis. Terão os escoteiros e sua patrulha, ou tropa, aoportunidade de conviver, aprender e enfrentar desafios variados.
b) Avaliar os recursos humanos.Temos adultos qualificados na chefia para executar tal atividade? Se não temos, devemos buscar a colaboração de especialistas: do rapel, guias, mergulhadores, professores, bombeiros, etc.? Tem número suficiente de chefia? De pais de apoio? Ao estabelecer as funções, ver se a tropa está completa, e se os jovens realmente estão preparados para participar. Se os jovens são inexperientes, devemos propiciar oportunidades, ao longo das reuniões, para capacitações nas técnicas escoteiras, palestras, avaliação e treinamento, etc.
c) Avaliar recursos materiais.O nosso equipamento é apropriado e está em boas condições? As barracas estão em ordem e tem lugar para todos? Fogareiro e lamparina em ordem? Tem gás e camisinha? Verificar a arrumação da caixa de patrulha antes do acampamento. Cada patrulha deve se encarregar de completar o que faltou, além de arrumar os materiais necessários para o acampamento. Por exemplo: camisinha para o lampião, mantimentos se precisar cozinhar, considerando todas as refeições (muitas patrulhas esquecem do café da manhã do segundo dia), caixa de primeiros socorros atualizada (repor e ver data de vencimento), entre outros.

d) Planejamento. | Cabe | aos | chefes
discutirem a programação antes do acampamento: qual o tema, data, local, horário, ponto de encontro, as atividades, horário das refeições, do banho, fogo de conselho, entre outros.
e) Visitar o local.É importante a escolha e reconhecimento do local, seja qual for a atividade. Todos os detalhes devem ser
reconhecidos pela chefia para que não
haja surpresas desagradáveis. Ao planejar

a atividade e reconhecer o local deve-se levantar as hipóteses de possíveis problemas para adotar ações preventivas, e/ou preparar os meios para executar ações corretivas.
f) Reconhecimento do local. O que devemos observar durante o reconhecimento?
- Socorro médico:tenha à mão o endereço e telefone de hospitais, médicos e farmácias próximos.
- Segurança: observar a vizinhança. Procure saber se o local é frequentado, e por que tipo de pessoas; se já houve ocorrência de furtos ou atos violentos.
- Animais: se há animais ferozes e peçonhentos, etc.
- Água potável: verifique se há e qual a abundância.
- Abrigos:se há celeiros, estábulos, galpões, grutas, etc.
- Solo: verifique se o solo é permeável.Evitar acampar sobre barro.
- Transporte: verifique quais os meios de transporte existentes, e qual deles é o mais adequado para chegar no local, (transporte coletivo ou carro de apoio), os custos, horários, veículos para casos de emergência, etc.
- Comunicação: localize um telefone para contato(público ou não) considere as possibilidades e limitações do telefone celular e/ou de equipamento de rádio.
- Abastecimento: verifique se perto do local da atividade existem mercados, mercearias, etc.Isso pode simplificar a logística, no que concerne a peso, volume ou perfectibilidade dos gêneros alimentícios a transportar.
- Regulamento: costumes ou regras de cada região e/ou do local.
- Atrativos: se há represa, rios, grutas, cavernas, piscinas, locais turísticos ou históricos, fábricas, plantações que podem visitar
g) Realização de percursos. É muito importante anotar os detalhes, as distâncias, tempo gasto, pontos de apoio, ponto de referência, os níveis de dificuldade, ponto de partida e ponto de chegada. Com desenho ou mapa.
h) Programação: Cabe à chefia planejar a programação do acampamento com os horários, atividades escoteiras, refeições, horário de banho, fogo de conselho, jogo noturno, devendo ser variada e atraente.

1.2.Durante

a) Mantenha os jovens ocupados com atividades atraentes, interessantes e equilibradas (o que não é sinônimo de cansá-los nem de assoberbá-los). Um dos objetivos é a convivência, e o cansaço pode impedir a consecução de objetivos importantes. (PROGRAMAÇÃO).
b) Observar os horários de dormir. (PROGRAMAÇÃO).
c) Mantenha os jovens bem alimentados. (NUTRIÇÃO).
d) Zele pela higiene de todos, pela higiene dos locais da atividade, pela higiene na alimentação e trate de todos os ferimentos, por menor que sejam. (SAÚDE).
e) Zele pela segurança de todos no uso de ferramentas e na aplicação das atividades. (SEGURANÇA).

1.3.Depois

a) Observar se o local está mais limpo e arrumado do que antes.
b) Faça os agradecimentos aos colaboradores presentes.
c) Exija limpeza e organização de todo o material usado;
d) Faça a prestação de contas;
e) Envie cartas de agradecimento (casonecessário);
f) Avalie a atividade junto aos jovens, à Corte de Honra e à chefia.

### 2. O QUE LEVAR PARA UM ACAMPAMENTO

É importante saber o que levar e saber também o que não levar, lembrar que um escoteiro tem de ser capaz de arrumar sozinho e carregar sua própria mochila; o excesso de peso e os materiais desnecessários podem causar dor nas costas, tanto os necessários que não foram levados também pode causar problema de saúde por falta.

Todos materiais têm que ser marcados com nome e identificação da pessoa ou da patrulha e colocados dentro de sacos plásticos impermeáveis para evitarem de serem molhar quando chover.

Para a seleção dos materiais ser bem-feita devem ser considerados fatores como: clima, tipo de acampamento, localização, existência de animais peçonhentos ou insetos, tipo de atividade, alimentação, caixa de primeiro socorro e medicamentos de uso próprio, etc.

C

2.1.O que levar para um acampamento de 2 dias?

CONTEÚDO

VESTUÁRIO | EQUIPAMENTOS
1 uniforme completo | 1 mochila
3 camisetas com o motivo escoteiro | 1 saco de dormir / cobertor
2 shorts ou bermuda | 1 isolante térmico / colchonete
1 agasalho para frio | 1 lanterna com pilhas novas e um conjunto extra
1 conjunto de moletom (roupa para dormir) | 1 garrafinha de água ou cantil
2 calcinhas ou cuecas | 1 repelente
2 pares de meias | 1 protetor solar
1 tênis sobressalente | 1 capa de chuva
1 chinelo de borracha para tomar banho | 6 sacos plásticos para roupas sujas
1 boné ou chapéu | Documento pessoal, documento de convênio médico e carteira de registro da UEB
1 roupa de banho | Autorização assinada e ficha médica
| Remédio de uso contínuo (entregar para a chefia com a prescrição médica)

HIGIENE
1 toalha de banho | ACONSELHÁVEL
1 toalha de rosto | 1 cabide
1 sabonete pequeno de viagem | 4 pregadores de roupa
1 pasta dental e escova de dente | 1 máquina fotográfica
1 pente ou escova de cabelo | 1 apito
1 desodorante não aerosol | 1 bússola
1 shampoo | 1 kit de primeiros socorros (1 por patrulha)
| 1 kit de costura (1 por patrulha)
ALIMENTAÇÃO | 1 caderno e lápis/caneta
1 prato (não descartável e não quebrável) | 1 luva de proteção (para as atividades de pioneria)
1 caneca de plástico ou alumínio (não descartável e não quebrável) | 1 rolo de papel higiênico pequeno

1 colher, garfo e faca (não descartável)
1 pano de prato
* Sugestão: uma sacola de costas para
colocar todos os utensílios dentro

Todo material deve estar identificado
Tudo deve estar embalado dentro de sacos plástico impermeável

O QUE É PROIBIDO LEVAR
1. Vidros, louças ou qualquer outro tipo de material que ao quebrar possa provocar ferimentos
2. Balas, chocolates, salgadinhos ou qualquer outro tipo de "contrabando".
3. Produtos em forma de aerosol tipo repelente, protetor solar, desodorante.
4. Medicação sem prescrição médica, a Chefia não irá oferecer nenhum tipo de remédio.
5. Celular, mini games, brinquedos, rádios, bugigangas.

2.2.A Caixa de Primeiros Socorros

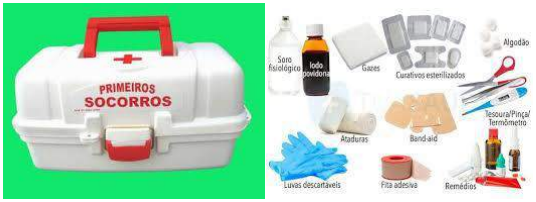
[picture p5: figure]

São várias as sugestões sobre o que contém dentro da caixa de primeiros socorros, os básicos são para curativos; os medicamentos somente são dados pela pessoa qualificada, é importante que contenha ficha médica atualizada de cada elemento, principalmente quem tem alergia a alguma coisa, e avisar a chefia o que usa no momento do acampamento, com receita, e: antibiótico. Deve trazer para acampamento quem usa medicamento de uso contínuo.ex: aerosol para asma.

Importante:

✓ Verificar a validade dos medicamentos antes de cada atividade
✓ Repor materiais do kit de primeiros socorros após cada atividade
✓ Dispor da ficha medica atualizada de cada escoteiro (durante acampamentos manter um histórico do uso de medicamentos, principalmente aqueles que necessitam de receita medica, ex. antibióticos)

Materiais:

* Atadura de crepom de tamanho pequeno e grande.
* Curativos esterilizados de 3 tamanhos: pequeno, médio e grande.
*Gazes 3 pacotes pequenos, e algodão
*Bandagem triangular (1,5m de base e 90 cm de lados) para fazer tipoia ou cobri lesão. * Esparadrapo e ou fita adesiva (micro pólen)
*Soro fisiológico 1 frasco e 5 bastonetes de soro fisiológico.
* Antisséptico em spray 1 frasco e ou 1 frasco de iodopovidona.
*band-aid 1 cx e 1 cx de cotonete.
*Luvas descartáveis.
* Álcool 70% 1 frasco pequeno.
*Sabonete antisséptico
*Termômetro,
* tesoura sem pontas.
* agulha de seringa, ou 1 pinça (paratirar fiapo)
*Amônia e vinagre (atividade no mato e no mar)
*Pomada antialérgico para picada de inseto, para contusão muscular, creme hidratante.

2.3.Telefones Importantes e Serviço de Apoio

É importante que cada patrulha tenha uma lista de telefone contendo: o contato dos chefes que acompanham a atividade externa, dos elementos e respectivos familiares (que consta na ficha de autorização), da Diretoria do grupo escoteiro, além do telefone de hospitais ou posto de saúde próximos do acampamento. Quem tem plano de saúde é bom ter a carteirinha e saber onde levar caso aconteça um acidente.

Hospital Universitário Evangélico de Curitiba Alameda Augusto Stellfeld, 1908
Fone: (41) 3240-5000

Hospital Universitário Cajurú
Av. São José, 300
Fone: (41) 3271-3000

Hospital Trabalhador,
Av.Republica Argentina 4406 Fone: (41) 3212-5700

### 3. ATENDIMENTO INICIAL À VÍTIMA DE TRAUMA

O atendimento inicial à vítima de trauma é composto por três etapas: 1ª Controle da cena, 2ª Avaliação primária e 3ª Avaliação secundária.

3.1.Controle da Cena

Controle a cena do acidente significa garantir a segurança no local e analisar o mecanismo de trauma.
Segurança no local: Antes de iniciar o atendimento à vítima, garantir a própria condição de segurança, a da vítima e a dos demais presentes. De forma alguma se exponha ao risco. Solicite ajuda especializada. Pode ser necessário isolar a área, sinalizar, acionar serviços de apoio.

3.2.Avaliação Primária

Avaliação primária serve para identificar situações de ameaça à vida e manejar de imediato a vítima. É feita sem mobilizá-la da posição inicial, salvo em condições especiais como: risco de explosão, incêndio, afogamento, desabamento.
Aproxime-se e imobilize a cabeça da vítima com uma das mãos. Pergunte-lhe como está. Determine se está responsiva (consciente, acordada). Tente tranquilizá-la e pergunte o que aconteceu.

Neste momento é verificado:
A. Via aérea com imobilização da cabeça
B. Respiração
C. Circulação e controle de hemorragia e de choque
D. Estado de consciência
E. Exposição e proteção da vítima

A. Via aérea com imobilização da cabeça

Por que é importante manter fixa a cabeça da vítima antes de qualquer contato verbal?
Vias aéreas com controle cervical: se a vítima não responde, está inconsciente ou desmaiada, a queda da língua contra a faringe (fundo da garganta) é causa frequente de obstrução de vias aéreas. Essa situação prejudica a passagem de ar e, consequentemente, impede a respiração.
Através da manobra de elevação do queixo, é possível tracionar a língua para frente e liberar as vias aéreas, garantindo a passagem de ar.

Manobra de elevação de queixo,sem trauma. Com trauma da coluna cervical

Manobra de elevação do queixo:
Colocar uma das mãos na testa da vítima e aplicar pressão firme para trás. Com os dedos da outra mão, segurar o queixo e elevá-lo para cima.
Cuidado: Não inclinar a cabeça da vítima de trauma para trás. Se ela apresentar trauma de coluna cervical, qualquer mobilização da cabeça pode provocar lesão na medula, com os danos irreversíveis (paralisia e até morte).
A cabeça e o pescoço da vítima não pode ser hiperestendidos, hiperfletidos ou rodados, para promover o estabelecimento da permeabilidade das vias aéreas.
Para a adequada avaliação das vias aéreas, a vítima deve estar deitada. Caso esteja de bruços (decúbito ventral) o socorrista gira o corpo “em bloco” de forma a manter alinhados cabeça, pescoço, ombros e tronco (manobra de rolamento 180º) Isso evita danos na medula, caso a vítima tenha fratura de coluna vertebral.

Sangue, vômitos, corpo estranhos também podem causa obstrução de via aéreas. A manobra indicada para desobstruir vias aéreas de sangue ou vomito é de rolamento 90º

Rolamento de 90 e 180º em pacientes com trauma de coluna.
B. Respiração

Para determinar presença ou ausência de respiração espontânea, aproxime seu ouvido da boca e nariz da vítima, enquanto mantém as vias aéreas desobstruídas.
Ver - observe o tórax se faz movimento para cima e para baixo.
Ouvir - ouça se há saída de ar durante a expiração.
Sentir - sinta se há fluxo de ar.

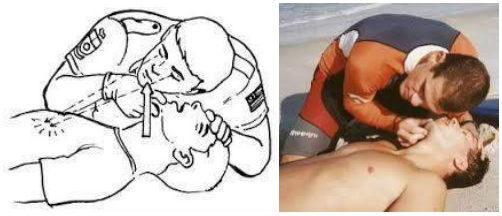
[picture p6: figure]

Ver, ouvir e sentir - respiração
Se a paciente não responde e ausência de respiração inicie a respiração artificial. Se presente analise sua qualidade e passar para o passo C.
C. Circulação e controle de hemorragia

Verifica a presença de circulação de sangue, se o coração está batendo, através da palpação de pulso da vítima ou na carótida ou radial. E também verificar se há sangramentos externos, mediante compressão direta dos ferimentos ou aplicação de curativos compressivos.

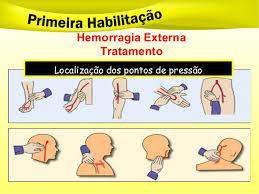
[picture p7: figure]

Circulação ausente - manobra de reanimação cardiopulmonar. Circulação presente - avance ao passo D

D. Estado de consciência (estado neurológico)

Avaliação do nível de consciência: verificar se a vítima se encontra:

A- Alerta: acordada, respondendo adequadamente às suas perguntas.
V – Reagindo à voz: olhos fechados que somente se abrem a estímulo. Responde à pergunta, às vezes de forma confusa, e voltar a fechar os olhos.
D- Reagindo à dor: somente reage com gemidos ou movimentos quando recebe estímulo doloroso (compressão na borda de um músculo-antebraço ou ombro) I-Não reagindo: não reage a qualquer estímulo (nem verbal nem doloroso)

Vítimas que apresentam nível de consciência alterado, merecem reavaliação e observação dos itens ABC (vias aéreas, respiração e circulação)

Tem no máximo 45 segundos para avaliação numa vítima em parada cardiorrespiratória, e iniciar RCP; acione os serviços especializados e informar a situação da vítima.

E. Exposição e proteção da vítima (aquecimento e remoção do paciente)

Resumo- Atendimento inicial à vítima(avaliação primaria)

1ª - Controle de cena – segurança no local, mecanismo de lesão.

2ª - Abordagem primária- A B C D E
A- vias aéreas com controle cervical:

1 -Aproximar-se- imobilizar a cabeça- verificar expansividade

2 - Acordado e conversando -passos A e B resolvidos – vias aéreas permeáveis e respirando.

3 - Manobra de abertura de vias aéreas (A resolvido) –checar respiração (ver, ouvir, sentir)
B –Respiração: conferir a da respiração.

Não respira: iniciar manobra de RCP (ressuscitaçãocardo respiratória)
C – Analisarcirculação com controle de hemorragia

1- (A vítima movimenta, respira ou tosse) – controlar hemorragia externa.

2– Sem circulação – RPC
D- Nível de consciência(estado neurológico da vítima) - A V D I

Aciona serviço de atendimento pré-hospitalar- repassar as informações corretamente.
E-Exposição e proteção da vítima:

Após todas avaliações, com atendimento de primeiros socorros e manter paciente aquecido e aguardar encaminhamento para atendimento secundário

Atendimento secundárioé com equipe de socorros, e hospitalar.

3.3.Avaliação Secundária (cuidado de ferimentos, fraturas e preparo para remoção)

Tem por objetivo procurar lesões não identificadas na avaliação primária, oferecendo cuidados para possível ferimento e fratura, confortando e aquecendo a vítima chegada do serviço de atendimento pré-hospitalar, prepará-la para ser removida.

3.3.1. Como fazer curativos leves no acampamento

Primeiro: para quem vai prestar os primeiros socorros tem que lavar bem as mãos com água e sabão, ou passar álcool 70% nas mãos; e usar luvas plásticas descartáveis, para que não tenha contato direto com sangue ou outros fluidos corporais da vítima e também para evitar contaminar a ferida.

Curativos simples:

1- Lavar a ferida com água fria corrente ou soro fisiológico.
2- Secar a ferida com gaze seca ou pano limpo;
3- Desinfetar a ferida com antisséptico, povidine, ou iodopovidona.
4- Cobrir a ferida pequena com band-aid, e se for maior, cubra com uma atadura de gaze e prenda com esparadrapo.
5- Curativos compressivos para as feridas com corte mais profundo e que sangra muito, levar para hospital, podendo até precisar de levar os pontos.
6- O curativo deve ser trocado sempre que estiver sujo ou molhado. (Use saco plástico em cima quando vai tomar banho) lavar a ferida.

3.3.2. Lesões musculares mais comuns numa atividade fisica
3.3.2.1. Contusão
3.3.2.2. Distensão Muscular

O uso de compressa fria tem que ser mais rápido possivel e proteger a pele se usa gelo,e imobilizar .

E CO

3.3.2.3. Entorse

É uma lesão dos ligamentos de uma articulação sem deslocamento das superfícies articulares. Distinguimos a entorse benigno (não há ruptura dos ligamentos) das entorses graves (há ruptura dos ligamentos). O tornozelo é a região do corpo mais
afetada por entorses. A entorse de tornozelo ocorre quando o sujeito “pisa em falso” no
chão e o pé realiza um movimento brusco. Pode ser em inversão, no qual o pé vira para fora (muito mais comum, representando cerca de 90% das entorses) ou em versão, onde o pé vira para dentro. Esse tipo de situação pode causar o comprometimento dos componentes agregados e deve receber análise de médico especializado para avaliar a situação do tornozelo e a eventual ruptura de ligamentos. Tratamento:
Compressa fria, gelo de 15 a 30 minutos. Imobilização e elevação do membro afetado. Repouso.

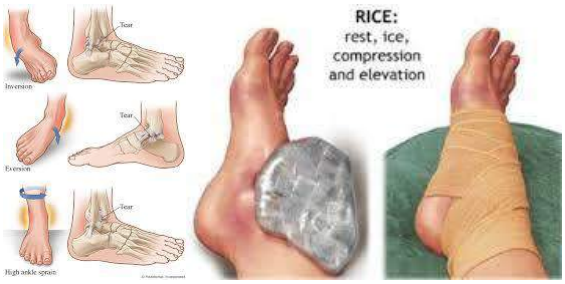
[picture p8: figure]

3.3.2.4. Luxação

Luxação é o deslocamento repentino, parcial ou completo das extremidades dos ossos que compõem uma articulação. É uma entorse mais grave, aqui se rompem não só os ligamentos, como também se descolam os ossos da articulação. Pode provocar lesões nas estruturas próximas. Luxação é diferente da fratura e da fissura, o osso sai do lugar, mas não se quebra nem racha, mas isso não exclui a possibilidade de também existir uma fratura naquele osso.
As articulações dos ombros, quadril, joelhos, cotovelos, punho e dedos das mãos são mais atingidas por trauma capaz de provocar luxações.
Sintoma: dor, edema, deformidade do local da lesão, incapacidade de mobilização.
Tratamento: gelo, imobiliza a articulação, tipoia. Não tente colocar o osso no lugar, procura médico, geralmente precisa de RX para saber se há fratura.

3.3.2.5. Fratura
Uma fratura ocorre quando há o rompimento ou quebra dos ossos, causados por algum impacto e/ou trauma de força considerável.Fraturassão comuns de acontecerem em acidentes que envolvam automóveis, quedas de determinadas alturas, ou em alguns casos, pesos que atinjam os pés ou as mãos. Dependendo do grau da lesão nos ossos, a fratura pode ser classificada como exposta, tipo de fratura de maior intensidade, quando há risco de infecção no local, pois o osso rompe a pele e causa sangramento, e a de menor intensidade, a fratura fechada, considerada uma trinca no osso, em que exista apenas uma fenda, e não propriamente uma fratura.

Uma fratura é detectada quando, após o impacto, houver inchaço no local da lesão, dorintensa incapacitante ou dificuldade de movimentação.
Existem diversos tipos de fraturas, sendo as mais comuns as dosossos dos pés, (http://www.centraldafisioterapia.com.br/especialidades/fisioterapia-ortopedica-fraturas-ossos-dos-pes)mãos, (http://www.centraldafisioterapia.com.br/especialidades/fisioterapia-ortopedica-fratura-maos-punhos)punhos, (http://www.centraldafisioterapia.com.br/especialidades/fisioterapia-ortopedica-fratura-maos-punhos)nariz, (http://www.centraldafisioterapia.com.br/especialidades/fisioterapia-ortopedica-fraturas-no-nariz)braços, (http://www.centraldafisioterapia.com.br/especialidades/fisioterapia-ortopedica-fratura-nos-bracos)pernas, (http://www.centraldafisioterapia.com.br/especialidades/fisioterapia-ortopedica-fraturas-ossos-pernas)cotovelo, (http://www.centraldafisioterapia.com.br/especialidades/fisioterapia-ortopedica-fratura-cotovelo)quadril, (http://www.centraldafisioterapia.com.br/especialidades/fisioterapia-ortopedica-fratura-quadril)tornozelo. (http://www.centraldafisioterapia.com.br/especialidades/fisioterapia-ortopedica-fratura-tornozelo) Os casos mais graves de fraturas são as que envolvem a cabeça, opescoçoe (http://www.centraldafisioterapia.com.br/especialidades/fisioterapia-ortopedica-fratura-pecoco) os ossos da coluna, em alguns casos é necessária a intervenção cirúrgica.

Fraturas mais frequentesem acampamento são geralmente causadas pela queda de uma altura, impacto de forças, batidas, e a mais importante de todas e mais perigosa é fratura do crânio e cervical.

3.3.2.6. Fratura Cervical

Em qualquer situação de acidentes quando há queda , pancada ,ou trauma que afeta a cabeça sempre usa o colete cervical,se tiver. Primeiros socorros :cuidado de não mexer muito a vítima ,imobilizar o pescoço com materia disponivel no local, e os cuidados no transporte da vítima

Coletes cervicais. Váriostipos usadospelos bombeiros, ou socorristas.

3.3.2.7. Matérias de improviso para mobilização

Materiais de improviso para imobilização cervical: Usar 2 bonés e uma tala.

Pode utilizar as materias que tem no local: toalhas, papelão, revistas, jornais, panos etc.E cuidados na remoçãoe e na transporte do paciente.Chamar equipe de socorros.

Fratura dos membros superiores:

São mais frequentes causada pela queda. Pode ser na clávicula, braços e punho e mão e nos dedos.Sintomas é dor, edema, equimose, incapacidade de movimentos, deformidade e lesão externa, Se for aberto ,terá exposição de fratura com lesão da pele e sangramento.

Primeiros socorros:

Fratura fechada. Imobilize e não tente colocar o osso no lugar.Aproveitando materias encontrados no ambiente para imobilizr o membro truamático.

Fratura aberta:

Primeiro lavar com o soro fisiologico, ou água limpa; parar o sangramento com gazer ou pano limpo, fazer curativo com compressas e depois imobilização do membro. Cuidado para não apertar demais o membro e não tente colocar o osso de volta. Cuidados na transportação do paciente e imediatamente remoção para hospital.

Aproveitar os materias existentes no ambiente para fazer atadura e imobilização.

3.3.3. Corpo estranho no olho e nos ouvidos

Corpo estranho nos olhos:

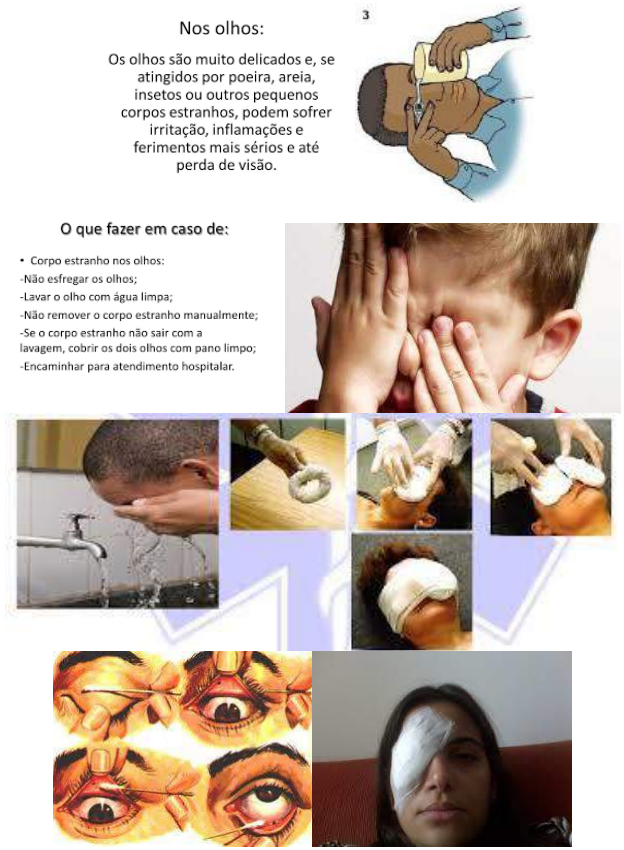
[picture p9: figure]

Caso não conseguir retirar o corpo estranho com cotonete ou lenço umedecida, fazer curativo e encaminhar o paciente para hospital.

Corpo estranho nos ouvidos:
Um corpo estranho no ouvido pode ser qualquer objeto localizado no canal auditivo externo (o canal que vai da membrana do tímpano até ao exterior do ouvido) e que normalmente não devia lá estar. Uma pessoa pode colocar um objeto no ouvido de propósito (tal como um cotonete) ou por acidente (por exemplo, um brinco pequeno). As crianças podem colocar muitos objetos pequenos diferentes nos seus próprios ouvidos ou nos ouvidos de outras crianças
O que não fazer?

Por vezes, um inseto pode rastejar ou voar para dentro do canal auditivo. Quer seja a extremidade de um cotonete quer um pequeno brinquedo, bicos de lápis, tampas de canetas, plásticos, pedaços de tampões de silicone, é frequente que aquilo que entra no canal auditivo não saia se existir um inseto no canal auditivo externo, nunca empurre o dedo para o canal, pois isso pode fazer com que o inseto o pique ou morda. Incline a cabeça com o ouvido afetado virado para cima; primeiro coloque uma lanterna, para ver se o inseto rastejar para fora do ouvido por si mesmo, mas, se não o fizer, coloque algumas gotas de óleo no ouvido. Isto irá sufocar o inseto. Depois o profissional pode remover o inseto instilando água limpa com seringa no canal ouvido.

No caso de os objetos não saírem, ou o paciente persistir com dor ou infecção do ouvido, consulta com um médico.

3.3.4. Picada de insetos

Estão por toda a parte os insetos, e embora a maioria não seja perigosa, sua picada ou ferroada incomoda. Mosquitos e carrapatos sugam o sangue humano para sobreviver. Já abelhas, vespas, aranhas e marimbondos, formigas, ferroam pessoas quando se sentem ameaçados ou quando querem proteger seus ninhos.
Ao picar ou ferroar, os insetos injetam veneno, responsável pela coceira e inchaço no local. Apesar da maioria das picadas e ferroadas não serem graves, o fato é que elas incomodam. Coçar a região pode fazer o veneno se espalhar e aumentar a coceira ainda mais. Perigoso são para o pessoal que tem alergia que podem causar choque anafilático com edema de glote, se não socorrer antes pode causa morte.

Picada de abelha e vespa: a picada ocorre quando o inseto insere na pele o seu ferrão como forma de defesa ao se sentir atacado. As vespas e abelhas que picam são sempre as fêmeas, pois os machos não possuem ferrão. Algumasespécies, como as abelhas comuns, sofrem auto amputação, ou seja, quando atacam perdem o ferrão e parte das estruturas abdominais, o que as leva à morte. Há espécie, porém, que não sofrem auto amputação e podem ferroar uma mesma vítima mais de uma vez. A quantidade de veneno injetada costuma ser maior nas espécies que perdem o ferrão. O primeiro ato do paciente deve ser a retirada imediata do ferrão da pele, pois ele permanece injetando veneno ainda por 1 ou 2 minutos. O ferrão pode ser retirado raspando as unhas na pele ou qualquer objeto rígido, como uma faca ou cartão de crédito.
Tratamento local:
Lave a pele com água e sabão e aplique compressas frias ou gelo local. Um analgésico simples pode ser útil. Aplique compressa com amônia, ou use uma pomada anti-histamínico pode ajudar a aliviar a coceira, ou de corticoide. Se piorar pode tomar por via oral, se não melhorar procure o médico.

Para quem tem alergia que pode causar choque anafilático ou edema de glote, sempre é bom trazer o medicamento de emergência, adrenalina intramuscular.

Prevenção:

Para evitar os mosquitos deve usar repelente que contém diethytoluamide (DEET) são mais eficazes, e use camisa de manga comprida ou calças compridas.

Proteção e prevenção das picadas:

Sempre olha no chão onde tem formigueiro, use calçado fechados onde tem maisformigueiros.

Outros Cuidados:

Os insetos gostam de produtos como perfumes, desodorantes, sabonetes, sprays e cremes, além disso roupas coloridas podem atrair insetos e devem ser evitadas.
Em plantas de floração de adição, excessos de comida, lixo e adubo áreas também atraem insetos devido ao seu cheiro e devem ser evitadas.
Frutos caídos, caixotes de lixo descobertos, etc. devem ser evitados. Podridões de frutos devem ser retirados do jardim regularmente e abranger todos os caixotes de lixo.
Ao comer ao ar livre, alimentos e bebidas devem ser mantidas cobertas uma vez que vespas e abelhas são atraídas por alimentos e bebidas doces

3.3.4.1. Escorpião

Classificados como aracnídeos, os escorpiões são animais invertebrados artrópodes que apresentam o corpo dividido em tronco e cauda. Geralmente, são animais discretos que, durante o dia, se alojam em esconderijos como tronco de árvores, pilhas de madeira ou tijolos, cercas, sob pedras, cupinzeiros, entulhos, mato, lixo, frestas nas paredes, saídas de esgoto, ralos, caixas de gordura, sapatos e tolhas, e durante a noite saem para caçar. Seu ferrão chama-se aguilhão e está localizado na ponta da cauda.
Conseguem sobreviver até dois anos sem se alimentar. Em relação à alimentação, ingerem preferencialmente grilos, baratas e moscas. Segundo alguns estudos, os escorpiões foram os primeiros artrópodes. São eles que dominaram o ambiente terrestre e atualmente tem-se conhecimento de aproximadamente 1600 espécies no mundo. Dois gêneros da espécie que merecem atenção:
- Escorpião amarelo: É encontrado nas regiões nordeste, sul e sudeste, precisamente em Santa Catarina, Minas Gerais, nas regiões do Vale do Paraíba, Rio Preto e na capital do Estado de São Paulo. Com tronco de cor escura e patas e cauda amarelos, pode atingir até 7 cm de comprimento. De hábitos noturnos, é facilmente encontrado em ambientes urbanos, vivendo em terrenos baldios e antigas construções.
- Escorpião marrom: Encontrado nos mesmos locais que o escorpião amarelo, incluindo Mato Grosso e Santa Catarina. Em São Paulo sua presença é bastante comum nas regiões do Morumbi, Pacaembu e ao longo do Rio Pinheiros. Sua cor varia de marrom-escuro a marrom-avermelhado com manchas escuras. Vivem em campos, matas ralas e fendas de barrancos.
Caso ocorra o acidente, recomenda-se: fazer compressas mornas e utilizar analgésicos para aliviar a dor até chegar a um serviço de saúde para que o médico possa avaliar a necessidade ou não de soro ou tomar outras medidas necessário.
O prognóstico do paciente com manifestações sistêmicas está diretamente relacionado à rapidez da administração do soro antivenenoso.

Primeiros socorros em caso de acidente:
Lavar o local da picada com água e sabão; não fazer torniquete ou garrote, não furar, não cortar, não queimar, não espremer, não fazer sucção no local da ferida e nem aplicar folhas, pó de café ou terra sobre ela para não provocar infecção; não ingerir bebida alcoólica, querosene, ou fumo, como é costume em algumas regiões do país; levar a vítima imediatamente ao serviço de saúde mais próximo para que possa receber o tratamento em tempo.
O tratamento, quando necessário, é feito com o soro antiescorpiônico (SAESC) ou o soro antiaracnídico (Tityus, Phoneutria e Loxosceles - SAA).

Como se prevenir?
Usar calçados e luvas nas atividades rurais e de jardinagem; examinar calçados e roupas pessoais, de cama e banho, antes de usá-las; não acumular lixo orgânico, entulhos e materiais de construção; vedar frestas e buracos em paredes, assoalhos, forros e rodapés; utilizar telas, vedantes ou sacos de areia em portas, janelas e ralos; manter limpos os locais próximos das residências, jardins, quintais, paióis e celeiros; combater a proliferação de insetos, principalmente baratas e cupins; preservar predadores naturais como seriemas, corujas, sapos, lagartixas e galinhas; limpar terrenos baldios pelo menos na faixa de um a dois metros junto ao muro ou cercas.
3.3.4.2. Taturanas ou Lagartas

A importância das lagartas de mariposas (lepidópteros) em saúde pública se deve aos efeitos causados pelo contato das cerdas de algumas espécies que contêm toxinas. Somente a fase larval (lagartas) desses animais é capaz de produzir efeitos sobre o organismo; as demais (pupa, ovo e adultos) são inofensivas, exceto as mariposas fêmeas adultas do gênero Hylesia (Saturniidae), as quais apresentam cerdas no abdômen que, em contato com a pele, podem causar dermatite pápulapruriginosa.
No Brasil, as espécies de lagartas que mais causam acidentes pertencem às famílias Megalopygidae (megalopigídeos) e Saturniidae (saturnídeos). Destaca-se entre os saturnídeos o gênero Lonomia, único responsável por envenenamento sistêmico, diferentemente das demais lagartas que causam apenas quadro local benigno.
As taturanas, também conhecidas como lagartas, são na verdade larvas que se tornam borboletas ou mariposas. Elas costumam aparecer mais em árvores nativas ou frutíferas como os coqueiros e pessegueiros, mas também podem ser encontradas em outros tipos de árvores ou arbustos.
Todos os tipos de taturana possuem cerdas pontiagudas, fazendo com que o veneno contido nas mesmas seja injetado na pele das pessoas que entram em contato com elas. Isso causa muita dor, uma sensação de queimação, o local fica bem vermelho e inchado.
Um tipo de taturana, conhecida como Lonomia, causa além desses sintomas, alterações na coagulação sanguínea, ou seja, faz com que ocorra sangramento gengival, urinário e em outras partes do corpo. Pode levar a graves complicações. Logo o socorro deve ser imediato no hospital mais próximo.
| Mais graves são os acidentes com taturanasLonomia obliqua e Lonomia
achelous, duas das poucas espécies potencialmente letais no país.
| O veneno delas tem componentes anticoagulantes que podem causar
hemorragia e insuficiência renal, e em alguns casos levam pessoas à morte, principalmente no sul do Brasil, onde são mais frequentes.
| Sintomas como dor de cabeça, náusea e vômitos também ocorrem nesses
casos, além de manchas roxas pelo corpo (não só no local da queimadura) de 3 a 4 horas após o contato com o animal. Todas essas são reações importantes que indicam que o acidentado deve ser levado rapidamente a um posto médico para receber o soro antilonômico, produzido em São Paulo pelo Instituto Butantã.
| Para identificar as taturanas do gêneroLonomia, observe se o animal tem o
corpo marrom com espinhos verdes em forma de pinheirinho, o dorso com listra marrom contornada de preto e algumas manchas brancas.

Compreenda os tipos de reações que podem surgir devido à picada da lagarta:
- Dermatite: coceira e dermatite de contato; inchaços; pequenas bolhas vermelhas; dor; vergões.
- Conjuntivite aguda, caso o cabelo atinja os olhos.
- Lepidopteríssimo: urticária (inchaços/feridas na pele que causam coceira); inflamação nas vias aéreas superioras; náuseas; vômitos; dores de cabeça; broncoespasmos.
- O contato com a lagarta da Dendrolimus pini asiática pode causar ferimentos que coçam, podendo até a levar a algumas formas de artrite (poli artrite/policondrite, osteoartrite crônica).
- Sangramento e complicações renais podem ocorrer após o contato com a lagarta “Lonomia” Sul-Americana. O contato com essa lagarta pode ser perigoso, e até fatal, caso você toque em inúmeras delas (como tocar uma vegetação habitada por muitas). Há um antídoto para o veneno dela.

Tratamento:
Acalme a pessoa que levou a picada.É mais fácil e menos estressante tratar uma picada caso você esteja calmo. Além disso, o veneno tende a viajar mais rápido quando o paciente não para de se mover
Remova a lagarta caso ela ainda esteja no corpo. Use fórceps ou tesouras, e não as mãos nuas. Coloque fita Scotch, fita celofane ou fita adesiva sobre a área da picada.
Remova a fita repetidamente. Isso removerá os espinhos, cabelos e toxinas. Cada vez que você colocar um pedaço de fita, utilize um novo para evitar adicionar mais efeito ao veneno. Depiladores faciais comerciais podem ser usados no lugar da fita.
Lave a área ferida usando água e
sabão. | Remova | todas as roupas
contaminadas e lave

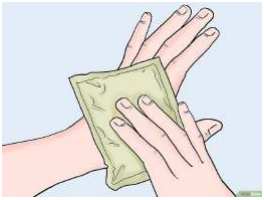
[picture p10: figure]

| | -as em água quente.
Aplique um pacote de gelo na área picada após lavá
| | -la. Quando a
sensação de dor reduzir (verifique após 15

-20 minutos), aplique uma pasta feita de bicarbonato de sódio e água.
Aplique um anestésico tópico, caso tenha acesso a algum. Analgésicos comuns, podem ser úteis.
O inchaço pode ser minimizado ao elevar a área da picada.
Você pode reaplicar o pacote de gelo a cada hora por 15
| | -20 minutos
durante o dia, se necessário. Um pano molhado pode substituir idealmente o pacote de gelo.
Monitore a picada.Fique atento ao aparecimento de pus, feridas, inchaços ou mudanças na coloração. Se os sintomas não melhorarem, busque atenção médica. Se o paciente sofrer de asma, febre do feno ou de outras alergias, ou se sintomas alérgicos surgirem, procure um médico imediatamente.

Dicas:
Não toque ou manuseie lagartas peludas ou de cores brilhantes. Essas características normalmente indicam a presença de venenos no inseto.
Não coce a picada.
Note a região geográfica em que você recebeu a picada e mantenha animais e crianças longes dela. Alerte oficiais caso haja um número anormal dessas criaturas lá. A não ser que você seja um profissional treinado, não crie animais selvagens como bichos de estimação. Se você quiser criar lagartas para que elas se transformem em borboletas ou mariposas, há inúmeros sites especiais e catálogos que podem lhe fornecer ovos e equipamento.
3.3.5. Acidentes com animais peçonhentos ou venenosos

Animais peçonhentos são reconhecidos como aqueles que produzem ou modificam algum veneno e possuem algum aparato para injetá-lo na sua presa ou predador. Os principais animais peçonhentos que causam acidentes no Brasil são algumas espécies de serpentes, de escorpiões, de aranhas, de lepidópteros (mariposas e suas

larvas), de himenópteros (abelhas, formigas e vespas), de coleópteros (besouros), de quilópodes (lacraias), de peixes, de cnidários (águas-vivas e caravelas), entre outros. Os animais peçonhentos de interesse em saúde pública podem ser definidos como aqueles que causam acidentes classificados pelos médicos como moderados ou graves.
3.3.5.1. Aranhas

São três os tipos (gêneros) de aranhas: Aranha-armadeira: também chamada de aranha-da-banana ou macaca, encontrada em várias regiões do país, com predomínio na região Sudeste e Sul; aranha-marrom, muito comum no Sul, principalmente no Paraná, e viúva-negra, mais encontrada no litoral do Nordeste. A tarântula ou aranha-de-jardim e as caranguejeiras: apesar de muito temidas, não causam acidentes de importância, assim como as aranhas domésticas que fazem teias geométricas (orbital).
Latrodectus(viúva-negra): Não é agressiva. A fêmea pode chegar a 2 cm e o macho a 2 a 3 mm. Tem atividade noturna e hábito gregário. Faz teia irregular em arbustos, gramíneas, cascas de coco, canaletas de chuva ou sob pedras. É encontrada próxima ou dentro das casas, em ambientes sombreados, como frestas, sob cadeiras e mesas em jardins.

Phoneutria(aranha armadeira ou macaca): Bastante agressiva, assume posição de defesa saltando até 40 cm de distância. O corpo pode atingir 4 cm, com 15 cm de envergadura. São caçadoras, com atividade noturna. Abriga-se sob troncos, palmeiras, bromélias, e entre folhas de bananeira. Pode se alojar em sapatos, atrás de móveis, cortinas, sob vasos, entulhos, material de construção etc.

Loxosceles(aranha-marrom): Não é agressiva, pica geralmente quando comprimida contra o corpo. Tem um centímetro de corpo e até três de comprimento
total. Possui hábitos noturnos, constrói teia irregular como “algodão esfiapado”.
Escondem-se em telhas, tijolos, madeiras, atrás ou embaixo de móveis, quadros, rodapés, caixas ou objetos armazenados em depósitos, garagens, porões, e outros ambientes com pouca iluminação e movimentação

Picada da aranha marrom

A evolução da picada da aranha marrom é bem variada, sendo os três primeiros dias os mais críticos. Acidentes com aranha marrom são típicos da região sul, por isso é muito importante, no caso de suspeita de picada, consultar um médico o mais rápido possível no posto de saúde ou na UPA para ser medicado ou tomar Soro antiloxoscélico (SALOx) ou Soro Antiaracnídico (SAAr). Depende da gravidade a ferida pode evoluir de necroses locais para problema sistêmico com hematúria (urina escura) e óbito.
As aranhas caranguejeiras (Ordem Mygalomorphae). Os sintomas mais frequentes são dor local pouco intensa discreto. Embora grandes e frequentemente encontradas em residências, não causam acidentes. Ao se sentirem ameaçadas, raspam as pernas traseiras contra o abdômen, liberando cerdas urticantes, que podem causar reações alérgicas e edema

A Lycosa ( tarântula) aranha do jardim e vive nos gramados geralmente não causa tantos problema de saúde não tem soro contra ela.

Primeiros socorros em caso de acidente

Lavar o local da picada com água e sabão; não fazer torniquete ou garrote, não furar, cortar, queimar, espremer ou fazer sucção no local da ferida, nem aplicar folhas, pó de café ou terra para não provocar infecções; não ingerir bebida alcoólica, querosene, ou fumo, como é costume em algumas regiões do país; levar a vítima imediatamente ao serviço de saúde mais próximo para que possa receber o tratamento adequado em tempo
Como tratar:
Dependendo dos sintomas, podem ser adotadas medidas para alívio da dor, como compressas mornas (acidentes por aranha-armadeira e viúva-negra). Havendo ou não melhora, o paciente deve ser levado ao serviço de saúde mais próximo para ser avaliada a necessidade de administração de soro específico.
Prevenção:
Usar calçados e luvas nas atividades rurais e de jardinagem; examinar calçados, roupas pessoais, de cama e banho, antes de usá-las; afastar camas das paredes e evitar pendurar roupas fora de armários; não acumular entulhos e materiais de construção; limpar regularmente móveis, cortinas, quadros, cantos de parede; vedar frestas e buracos em paredes, assoalhos, forros e rodapés; utilizar telas, vedantes ou sacos de areia em portas, janelas e ralos; manter limpos os locais próximos das casas, jardins, quintais, paióis e celeiros; evitar plantas tipo trepadeiras e bananeiras junto às casas e manter a grama sempre cortada; limpar terrenos baldios pelo menos na faixa de um a dois metros junto ao muro ou cercas.
Utilizar botas de cano longo, ou botinas com perneiras, luvas e camisas com mangas longas quando fazer trabalhos de coleta de lixo, manuseio de pilhas de madeira, materiais de construção e outros.
3.3.5.2. Cobras/Serpentes

Acidente ofídico ou ofidismo é o quadro de envenenamento decorrente da inoculação de toxinas através do aparelho inoculador (presas) de serpentes. No Brasil, são quatro os tipos de acidentes ofídicos:
Acidentes botrópicos: São causados por serpentes da Família Viperidae, dos gêneros Bothrops e Botrocophias (jararacuçu, jararaca, urutu, caiçaca, comboia). É o grupo mais importante, com 29 espécies em todo o território nacional, encontradas em ambientes diversos, desde beiras de rios e igarapés, áreas litorâneas e úmidas, agrícolas e periurbanas, cerrados, e áreas abertas. Causam a grande maioria dos acidentes ofídicos no Brasil. Tem dentição solenóglifa;

Acidentes crotálicos: São causados pelas cascavéis (Família Viperidae, espécie Crotalus durissus). São identificadas pela presença de um guizo, chocalho ou maracá na cauda e têm ampla distribuição em cerrados, regiões áridas e semiáridas, campos e áreas abertas. Tem dentição solenóglifa;
Acidentes laquéticos: Também são causados por serpentes da Família Viperidae, no caso a espécie Lachesis muta (surucucu-pico-de-jaca). A pico-de-jaca é a maior serpente peçonhenta das Américas. Seu habitat é a floresta Amazônica e os remanescentes da Mata Atlântica. Tem dentição solenóglifa;
Acidentes elapídicos. São causados pelas corais-verdadeiras (Família Elapidae, gêneros Micrurus e Leptomicrurus). São amplamente distribuídos no país, com várias espécies que apresentam padrão característico com anéis coloridos. Tem
dentição | proteróglifa.

O envenenamento ocorre quando a serpente consegue injetar o conteúdo de suas glândulas venenosas, o que significa que nem toda picada leva a envenenamento.
Na maioria dos casos, o diagnóstico clínico permite a identificação do tipo de envenenamento, uma vez que a identificação do animal é pouco frequente. Os sinais e sintomas decorrentes do envenenamento ofídico dependem das atividades presentes nos quatro tipos de veneno (botrópico, laquético, crotálico ou elapídico), cujos efeitos podem ser locais ou sistêmicos.

Jararaca:

Acidente botrópico: A região da picada apresenta dor e inchaço, às vezes com manchas arroxeadas (edemas e equimose) e sangramento pelos pontos da picada, em gengivas, pele e urina. Pode haver complicações como grave hemorragia em regiões vitais, infecção e necrose na região da picada e insuficiência renal.
Acidente laquético: Quadro semelhante ao acidente por jararaca, a picada pela surucucu-pico-de-jaca pode ainda causar dor abdominal, vômitos, diarreia, bradicardia e hipotensão.
Acidente crotálico: Na picada por cascavel, o local da picada muitas vezes não apresenta dor lesão ou evidente, apenas uma sensação de formigamento; dificuldade de manter os olhos abertos, com aspecto sonolento (fácies miastênica), visão turva ou dupla, mal-estar, náuseas e cefaleia são algumas das manifestações, acompanhadas por dores musculares generalizadas e urina escura nos casos mais graves.

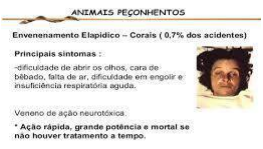
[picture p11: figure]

Acidente elapídico: O acidente por coral-verdadeira não provoca no local da picada alteração importante. As manifestações do envenenamento caracterizam-se por dor de intensidade variável, visão borrada ou dupla, pálpebras caídas e aspecto sonolento. Óbitos estão relacionados à paralisia dos músculos respiratórios, muitas vezes decorrentes da demora na busca por socorro médico

Cascavel:

l

Em caso de acidente deve-se fazer o seguinte procedimento:

- Deixe a vítima em repouso absoluto; não deixar que o acidentado ande ou corra.
- Mantenha a parte afetada em posição horizontal, para dificultar a difusão do veneno;
- Lave o local com água e sabão;
- Afrouxe as roupas da vítima, procure retirar acessórios que dificultem a circulação sanguínea da vítima;
- Tranquilize a vítima;
- Dirigir-se urgentemente a um serviço médico. Procure socorro, principalmente após trinta minutos em que ocorreu o acidente.

Não se deve fazer:

- Não amarrar o membro acometido. O torniquete ou garrote dificulta a circulação do sangue, podendo produzir necrose ou gangrena e não impede que o veneno seja absorvido.
- Não cortar o local da picada. Alguns venenos podem inclusive provocar hemorragias e o corte aumentará a perda de sangue.
- Não chupar o local da picada. Não se consegue retirar o veneno do organismo após a inoculação. A sucção pode piorar as condições do local atingido.
- Não colocar substâncias no local da picada, como folhas, querosene, pó de café, pois elas não impedem que o veneno seja absorvido, pelo contrário, podem provocar infecção.
- Evitar que o acidentado beba querosene, álcool ou outras bebidas. Além de não neutralizarem a ação do veneno, podem causar intoxicações.

Não andar descalço. Usar luvas de couro nas atividades rurais e de jardinagem, nunca colocar as mãos em tocas ou buracos na terra, ocos de árvores, cupinzeiros, entre espaços situados em montes de lenha ou entre pedras. Quando entrar em matas de ramagens baixas, ou em pomar com muitas árvores, parar no limite de transição de luminosidade e esperar a vista se adaptar aos lugares menos iluminados. Não depositar ou acumular material inútil junto à habitação rural, como lixo, entulhos e materiais de construção.

### 4. AFOGAMENTO

4.1.Como agir

- Peça socorro a pessoas habilitadas (salva-vidas) e não tente fazer o salvamento amenos que tenha sido treinado para isso
- Retire a vítima da água usando algum objeto que flutue, puxando-a para um local seguro. Evite tentar o salvamento sozinho e sem recursos materiais (boia, corda, embarcação etc.)
- Se a vítima estiver lúcida, coloque-a deitada e vire-a para a direita, com acabeça mais elevada em relação ao tronco.
- Acalme-a, mantenha-a aquecida e, seela ingeriu boa quantidade de líquido, transporte-a imediatamente ao hospital
- | Se | o | afogamento | originar | parada | cardiorrespiratória, | realize | a
reanimaçãocardiopulmonar (ver item “parada cardíaca”) ou solicite que alguém
habilitado paratal faça isso.
- A vítima deve ser conduzida o mais rápido possível ao hospital.
- Em caso de hipotermia (temperatura corporal abaixo de 35° C), aqueça-a e conduza-a ao hospital.

4.2.Os cuidados nos primeiros socorros do afogamento

4.2.1. Máscara de respiração boca a boca

4.3.Reanimação Cardiorrespiratória

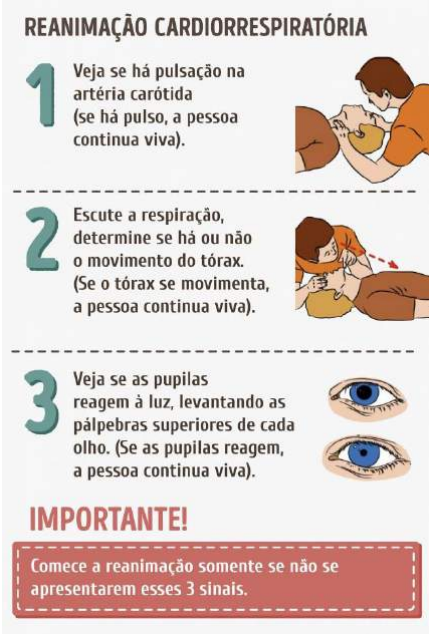
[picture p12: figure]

4.4.Como fazer a Ventilação Artificial dos Pulmões

4.5.Como Fazer a Massagem Cardíaca Externa

4.6.Como prevenir

- Após ingerir alimentos espere no mínimo 1 hora para entrar na água
- Se ingerir bebida alcoólica, não entre na água
- Evite pular na água em locais desconhecidos, pois muitas pessoas se acidentam batendo com a cabeça em pedras, galhos e no fundo de rios
- Procure se banhar em locais onde haja salva-vidas, pois a quase totalidade dos
- Afogamentos acontecem em locais desprotegidos
- Respeite a sinalização do local e a orientação dos salva-vidas
- E fornecer dicasvaliosas sobre correnteza, buracos e locais de maior risco para banho

### 5. PREVENCAO CONTRA RAIOS

5.1.Como se Formam os Raios

A falta de para-raios em épocas de temporais pode representar sérios prejuízos, pois a descarga elétrica de um raio sobre uma antena (televisão, rádio) ou sobre um poste de energia elétrica causa a queima de
equipamentos | domésticos | (eletrodomésticos,
computadores, etc.).

O raio representa também graves riscos para as pessoas, principalmente aquelas surpreendidas debaixo de árvores ou em áreas descampadas, ou ainda, que estejam trabalhando próximo a estruturas metálicas. Por ano, quase mil pessoas são vítimas de raios em todo o país - não há uma estatística precisa. A maioria sobrevive, porque são atingidas indiretamente, por uma faísca lateral ou porque estão próximas ou encostadas no ponto que sofreu o choque direto.
O raio é uma descarga elétrica que ocorre entre a nuvem carregada de eletricidade e a terra, mais precisamente entre a nuvem e o ponto mais próximo que esteja na terra (normalmente para-raios existentes nos edifícios). Na ausência do para-raios a descarga poderá ocorrer sobre árvores isoladas, postes, mourões de cerca, etc., principalmente nas áreas rurais.
Uma descarga elétrica dessa natureza possui uma potência média de 15.000 ampères. Para se ter uma ideia, um chuveiro apresenta potência de 30 ampères e quem já tomou um choque sabe o quanto perigoso pode ser. Acima de 500amperes já pode causar morte.
5.2.Como se prevenir de raios
- Durante as tempestades fique em casa.
- Saia somente se for absolutamente necessário.
- Não retire nem coloque roupa em varais de arame durante a tempestade.
- Mantenha-se afastado e não trabalhe em cercas, alambrados, linha telefônicas ou elétricas e estruturas metálicas.
- Não manipule materiais inflamáveis em recipientes abertos.
- Não operar tratores ou máquinas, especialmente, para rebocar equipamentos metálicos.
- Se você estiver viajando permaneça dentro do automóvel; os automóveis oferecem uma excelente proteção contra raios.
- Busque refúgio no interior de edifícios.
- Mantenha-se longe de árvores isoladas.
- Não permaneça dentro d'água durante as tempestades.
- Em casa, permaneça longe de portas e janelas.
- Evite áreas altas, busque refúgio em lugares baixos.
- Durante uma tempestade, não utilize aparelhos eletrodomésticos, mantenha-os desligados das tomadas e, também, desconecte da antena externa o televisor, assim você estará reduzindo danos.
- Use o telefone somente em uma emergência, os raios podem alcançar a linha telefônica aérea.
- Ao sentir carga elétrica em seu corpo (caracterizada por eriçamento do cabelo e formigamento da pele) jogue-se ao chão.
- Preste atenção à previsão do tempo para o princípio e fim da tarde, quando ocorre a maioria das trovoadas. Tenha um plano de fuga para qualquer atividade ao ar livre e afaste-se dos cumes das montanhas antes do meio-dia. Se tiver de fazer uma longa travessia de barco, tenha especial atenção. As canoas são um dos lugares mais expostos que existem

- Com mau tempo, evite árvores altas, picos desprotegidos, campos abertos e ou mesmo praias e piscinas.
- Na floresta, procure um conjunto de árvores de altura regular e numa zona baixa, mas longe d'água. Afaste-se de troncos e raízes.
- Se for apanhado em céu aberto, evite árvores isoladas, faça do corpo uma "bola com pés", acocorando-se com eles o mais junto possível. Não toque com as mãos no chão.
- Para minimizar o número de pessoas afetadas por um raio, não se junte em grupo. A corrente elétrica pode passar de uma pessoa para outra sem que elas se toquem. Afaste-se de objetos metálicos, especialmente armações de tendas e barracas ou cercas de arame, uma vez que se trata de bons condutores.
- Quando acampar, monte sua barraca longe de lugares com maior probabilidade de queda de um raio, tais como, árvores altas e isoladas.

- Aprenda a fazer reanimação cardiopulmonar. Cerca de 20% das vítimas morrem, mas muitas vezes podem ser salvas se tratadas de imediato.

▪
- Certifique-se de que a tempestade passou completamente antes de prosseguir seu caminho. Muita gente morre antes do clímax de uma tempestade por se aventurar cedo demais.

▪

Assim que a corrente flui através de uma resistência, a energia é depositada sob a forma de calor. As correntes de alta tensão são geralmente definidas como superiores a 1000 V, embora haja evidências de que o risco para lesão elétrica grave e fatal ocorra com tensões acima de 600 V.

As correntes elétricas podem causar contração tetânica flexora em membros, quando o fluxo de corrente passa através do tronco e as pernas podem causar arqueamento em opistótono e posturas e movimentos involuntárias da perna. Essas contrações musculares involuntárias podem ser muito fortes, impulsionando a pessoa a partir de uma fonte de tensão, e produzem trauma mecânicos

Os contatos de alta tensão em correntes AC e DC também são mais propensos a produzir uma contração violenta de um único músculo esquelético, que tende a jogar a vítima para longe da fonte, e eventualmente causar fraturas e luxações, especialmente emregião de ombros.

A corrente elétrica pode induzir parada cardíaca imediata por arritmias e alterações neurológicas como parada respiratória e convulsões.

A principal lesão encontrada em lesões por corrente elétrica são queimaduras e histologicamente é encontrada nestes pacientesnecrose de coagulação.

5.3.Efeitos dos Choques Elétricos em Função do Trajeto

O trovão pode ser usado para calcular qual a distância de um raio. Quando você Enxergar o clarão, comece a contar os segundos até escutar o trovão. Divida o número de segundos por três (3) e você terá a distância aproximada do raio em quilômetros.
A regra dos “30-30”: O primeiro “30”: Quando o tempo entre ver os relâmpagos e ouvir o trovão é de 30 segundos ou menos, então você está em perigo e deve procurar abrigo apropriado,
O segundo “30”: Atividades ao ar livre não devem ser retomadas até 30 minutos após o último raio é visto ou o último trovão é ouvido.
Não existe lugar seguro em ambiente externo como montanhas, pastos, etc.
Barracas não oferecem proteção alguma

Em caso de raios em campo aberto não fique em grupo, separe-se dos demais em torno de 5 metros.

Livre-se de equipamentos metálicos como por exemplo um bastão de caminhada.
Não se abrigue em árvores isoladas, ao invés procure desfiladeiros ou vales.

No caso de pegar uma tempestade elétrica na montanha não existe muito o que fazer já que não existe um lugar isolado com para-raios

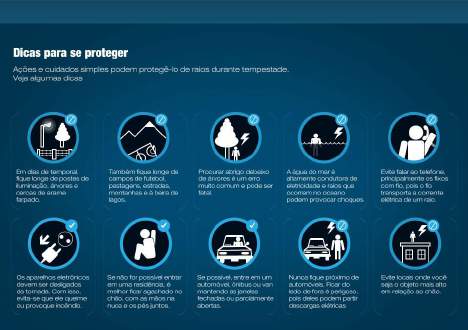
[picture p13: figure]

As lesõs cuasado pelo raio, ou eletricidade.

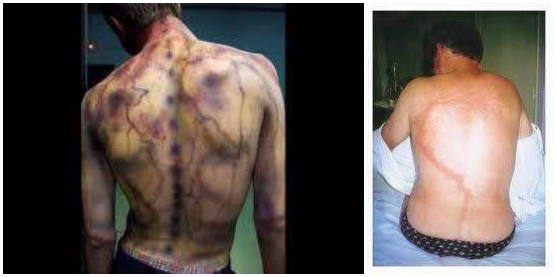
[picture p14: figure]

Figuras de Lichtenberg é caudado pela eletricidade com ruptura de capilares sanguíneo

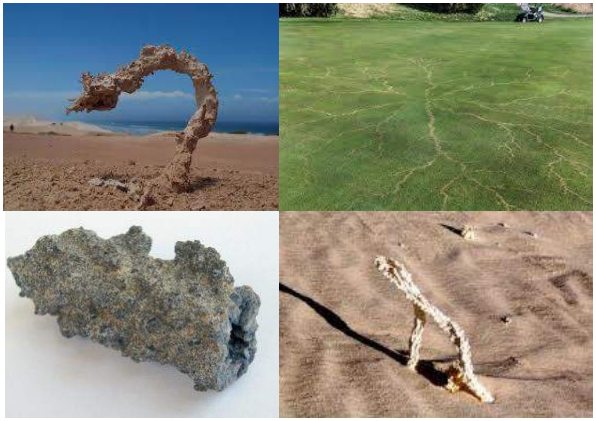
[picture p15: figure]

Raios caem em vários locais diferentes, e quando caem na areia, formam uma estrutura conhecida como fulgurito ou raio petrificado. Essas verdadeiras obras de arte se formam devido aos 1800º C com que os raios atingem o solo.
Com essa enorme temperatura, a areia praticamente derrete e forma uma estrutura que em geral é parecida com um tubo, é oca, tem a aparência vítrea, e como os grãos de areia que ficam por fora são semiderretidos, a aparência dos fulguritos é áspera.

### 6. ENGASGAMENTO

Engasgamento é: quando alimento sólido ou liquido entra pela via errado para traqueia a, isso causa obstrução parcial ou total da entrada do ar para o pulmão e pode levar a asfixia em pouco minutos, a vítima pode morrer por falta de oxigênio.
Pode ser causado por qualquer objeto como: balas, grão de arroz, feijão, milho, moeda, espinha de peixe até a própria saliva. As crianças pequenas são grande vítima de engasgo. Qualquer objeto pequeno pode causar isso, principalmente quando comemos e falamos ao mesmo tempo.
Quando encontra a pessoa engasgando, certifique-se que a pessoa esteja realmente com dificuldades para respirar. Alguns sinais são característicos: ela tenta falar e a voz não sai, fica agitada e confusa, levando as mãos para a garganta. A pele pode mudar de cor, passando a ficar azulada o que indica baixa oxigenação do sangue.

6.1.Como Evitar Asfixia por Engasgo

6.2.A Manobra de Heimlich para Desengasgar

Inicia aplicação da manobra de Heimlich quantas vezes forem necessárias

6.3.Perda de Consciência

Em termos médicos chamada de síncope, acontece quando a quantidade de sangue rico em oxigênio (arterial) que alcança o seu cérebro não é suficiente. Sem oxigenação adequada, o metabolismo do cérebro reduz-se o que causa perda breve e transitória da consciência até que o fluxo de sangue se restabelece.

Primerios socorros : Coloque cabeça para baixo entre as pernas: para pacientes conscientes:

Para pacientes inconscientes elevar as pernas, ou em posição de segurança deixar os membros inferiores mais alta que o corpo.

### 7. INSOLAÇÃO

7.1.Causas
A insolação é causada por situações em que a pessoa está em ambientes muito quentes ou faz esforço físico que eleva a temperatura do corpo, como:
- Passar o dia sob o sol sem protetor solar (na praia, por exemplo)
- Praticar atividades extenuantes
- Usar excesso de roupas
- Ficar desidratado por muito tempo.

7.2.Sintomas
A insolação causa sintomas que aparecem aos poucos, como
- Cefaleia (dor de cabeça) (http://www.minhavida.com.br/saude/temas/dor-de-cabeca)
- Tonturas
- Náuseas (http://www.minhavida.com.br/temas/N%C3%A1useas)
- Pele quente e seca (sem suor), às vezes avermelhada
- Pulso rápido

- Temperatura corporal elevada
- Distúrbios visuais
- Fraqueza muscular
- Confusão. (http://www.minhavida.com.br/temas/Confus%C3%A3o)
Outros sintomas surgem de repente, como:
- Respiração rápida e difícil
- Palidez (http://www.minhavida.com.br/saude/temas/palidez)
- Desmaios
- Extremidades arroxeadas.

7.3.Prevenção
Use filtro solar, use boné ou chapéu que protege do sol, beber muita água, use camisas de manga comprida e óculos escuro.

### 8. INTERMAÇÃO:

É uma enfermidade provocada pela ação do calor em ambientes com temperatura muito alta, locais onde estejam em funcionamento fornos, fogões, caldeiras, forjas, fundições, etc. Ainteraçãoacarreta uma série de alterações no organismo, com graves consequências para a saúde da vítima.

Perturbação do organismo causada por excessivo calor em locais úmido e não arejados.

8.1.Sintomas

- Dor de cabeça e náuseas.
- Palidez acentuada
- Sudorese (transpiração excessiva)
- Pulso rápido e fraco
- Temperatura corporal ligeiramente febril.
- Câimbra no abdome ou nas pernas
- Inconsciência

Remova a vítima para um lugar fresco e arejado, afrouxe as vestes da vítima. Mantenha o acidentado deitado com a cabeça mais baixa que o resto do corpo.

### 9. HIPOGLICEMIA

É o baixo nível de açúcar no sangue e pode acontecer com diabéticos ou não.

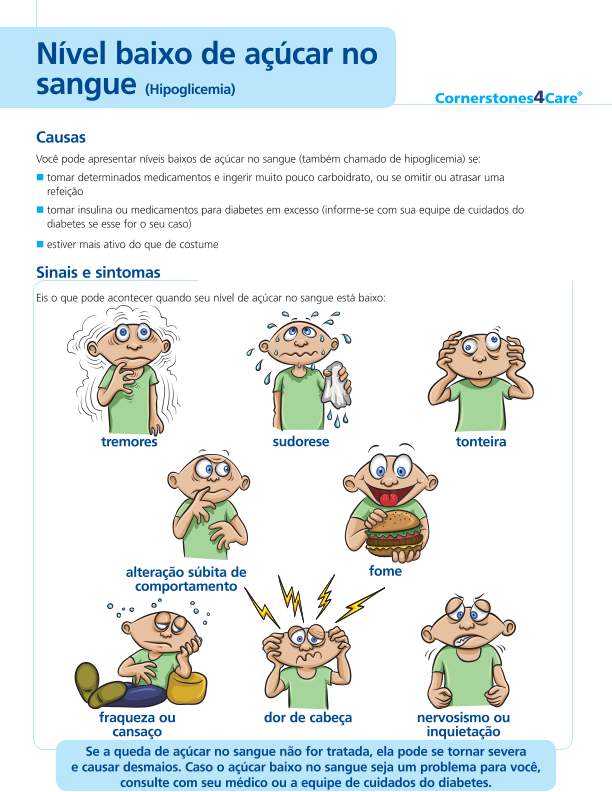
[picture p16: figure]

9.1.Como tratar

10.HIPOTERMIA

Quando acampamos ou realizamos alguma atividade ao ar livre, estamos sempre à mercê das condições climáticas. Frio, vento e chuva nem sempre são aliados dos aventureiros. Em situações de frio extremo, a temperatura do corpo pode acabar caindo e causando um quadro de hipotermia.

### 10.1. Classificação

Hipotermia Aguda: É caracterizada pela perda de temperatura, de forma brusca e rápida, devido à exposição intensa ao frio. Essa queda corporal de forma agressiva é causada pela incapacidade do organismo de suprir e manter a energia interna, devido ao fato de ter sido esfriado também. É muito comum em casos de exposição à Neve, Tempestades, etc.

Hipotermia Subaguda: É caracterizada pela perda de temperatura corporal, gradualmente, em períodos mais longos até o desgaste total das reservas do organismo para suprir o calor interno.

Hipotermia Crônica: A mais comum em centros urbanos, principalmente em estações como o Inverno, onde o índice de resfriados e enfermidades acontece com maior frequência. A Hipotermia Crônica é causada por consequências de alguma patologia.

Os sintomas mais comuns de hipotermia são tremores, esfriamento das mãos e pés, dormência nos membros, pouca energia, dificuldade em respirar, pulsação lenta, inchaço na face, perda de controle da bexiga. Em estágios mais avançados a hipotermia causa perda de memória, perda de controle dos membros superiores e inferiores, perda dos sentidos, perda da pulsação e pupilas dilatadas.

A hipotermia é causada devido a uma exposição intensa ao frio, em vários aspectos, como:

- Em ambientes frios, quando não há um aquecimento corporal que é fornecido pelas roupas, protegendo todos os membros, inclusive a cabeça.
- Exposição a chuvas e ventos frios. Os contatos da água com brisas geladas fazem com que a temperatura corporal abaixe.
- Pessoas que sofreram acidente, que tomam certos tipos de medicamentos, estão susceptíveis a terem hipotermia.
- Bebês mantidos em ambientes frios também estão aptos a terem hipotermia, se não houver um aquecimento correto de todo seu corpo

### 10.2. Tratamento

- Mantenha a pessoa seca: Se a pessoa estiver molhada, a primeira coisa a fazer é tirar a roupa úmida ou molhada e vestir a pessoa com uma roupa seca.
- Aqueça o máximo possível: Agasalhe a pessoa o máximo possível. Pode ser com roupas, com um saco de dormir (ou mais de um), cobertores, ou ainda com manta térmica de alumínio. Outra dica para aquecer a pessoa é esquentar água e colocar em um recipiente, como um soquete, cantil ou garrafa pet, e colocar isso nas axilas e virilha, que são os locais onde se encontram as maiores artérias do corpo.
- Manter próximo a uma fonte de calor: Se tiver uma fonte de calor, como uma fogueira, coloque a vítima próximo a ela.
- Dê bebidas quentes: Para auxiliar a recuperação da temperatura corporal normal, se possível dê líquidos quentes para a vítima, como chocolate quente, leite quente, chá ou até mesmo água quente.

- Monitore a vítima: Fique vigiando as funções vitais como o batimento cardíaco e a temperatura.
- Não deixe a pessoa dormir: Jamais deixe a vítima dormir, já que a hipotermia é chamada também de morte silenciosa. Quando está em seu estado terminal, com a diminuição das suas funções vitais, a vítima tende a adormecer e vir ao óbito.
- Dependendo da intensidade da hipotermia, ela pode atingir o sistema imunológico e ainda causar algum problema cerebral. Mesmo que a vítima pareça reabilitada, é importante levá-la ao hospital para se certificar de que não houve alguma lesão permanente.

### 10.3. Prevenção:

Para evitar a hipotermia alguns cuidados devem ser mantidos, como:

- Ao se expor em ambientes frios, utilize vestimentas adequadas. Proteger a cabeça é fundamental, uma vez que até 20% do calor corporal é perdido através dela.
- Caso estiver molhado devido a chuvas ou outras situações, troque de roupas imediatamente, uma vez que a roupa molhada diminui sua capacidade de manter a temperatura interna.
- Realizar movimentos corporais, exercícios, para ajudar o sangue circular corretamente, diminuindo sua contração

11.ESTADO DE CHOQUE

O choque acontece quando o fluxo de oxigênio para as células do corpo diminui ou para por completo. Ele vai aumentando gradativamente e causando danos nos tecidos de acordo com sua extensão, até o momento em que o coração não recebe oxigênio suficiente e para de bater, causando a morte.

Esta emergência pode ter diversas causas: grande perda de sangue, infarto, aceleração do coração, queimaduras graves, traumatismos de crânio, tórax e abdômen, envenenamentos, afogamento, choque elétrico, picadas de animais venenosos, mudança brusca de temperatura e infecção.
Se a vítima apresentar algum dos sintomas abaixo, é necessário agir rapidamente, principalmente para tentar evitar que ela entre em choque.

### 11.1. Como reconhecer

- Pele pálida, úmida, pegajosa e fria
- Orelhas, lábios e pontas dos dedos arroxeadas
- Suor na testa e nas palmas das mãos
- Muita sede
- Pupilas dilatadas
- Medo
- Fraqueza geral
- Pulso rápido e fraco
- Sensação de frio
- Respiração rápida, curta, irregular ou muito difícil
- Pupilas nublada
- Náuseas e vômitos
- Confusão mental
- Perda total ou parcial de consciência
- Aceleração dos batimentos

### 11.2. Como agir

- Deite a vítima de costas. Afrouxe as roupas no pescoço, no peito e na cintura. Em seguida, verifique se há prótese dentária, objetos ou alimento na boca e retire-os
- Eleve as pernas da vítima em relação ao restante do corpo com uma almofada ou qualquer outro objeto (se não houver fraturas ou ferimentos no tórax e na cabeça)
- Se ela estiver inconsciente, ou se estiver consciente, mas sangrando pela boca ou pelo nariz, deite-a de lado, apoiada sobre o lado esquerdo
- Caso a vítima pare de respirar, inicie a respiração boca a boca. Coloque a cabeça dela para trás, para que a língua não bloqueie a passagem de ar e tampe as narinas dela. Sopre dentro da boca da vítima até ver o peito se mexer. Repita o procedimento até a emergência chegar
- Se a pessoa estiver fria, agasalhe-a
- Mantenha-a calma e observe se ocorre alguma mudança grande no estado da vítima para informá-la à equipe de socorro

12.CONVULSÃO

É uma desordem temporária do cérebro, durante breve período de tempo, o cérebro deixa de funcionar normalmente, passando a enviar estímulos desordenados ao resto do corpo, num curto –circuito. Essa situação pode resultar em contrações involuntários dos músculos, acompanhadas de abalos mais ou menos violentos de partes do corpo. É a crise convulsiva, também conhecida como ataques epilépticos. As crises convulsivas manifestam-se de várias maneiras: o tipo como Grande Mal.

### 12.1. Causas

Em pessoas previamente sadias: choque elétrico, traumatismo de crânio, baixa do açúcar no sangue, abstinência de álcool no alcoolista, abuso de drogas como overdose de cocaína, meningite, trauma do parto, tumores cerebrais, doença cerebrovascular (AVC)
Alguns fatores podem desencadear crise convulsivas:
Luzes piscando - alguns doentes têm crises quando veem televisão, jogam no computador, ou frequentam discotecas; privação de sono- dormir pouco ou ficar sem dormir, ingestão de bebida alcoólica, febre, ansiedade, cansaço. Drogas ilícitas alguns medicamentos.
A crise convulsiva não é transmissível. Não há risco nenhum de alguém desenvolver a crise pelo fato de prestar assistência à vítima em estado de convulsão

### 12.2. Sinais e Sintomas

Perda súbita de consciência, às vezes precedida de grito.
O paciente cai ao chão, iniciando-se uma sequência de três fases:
1. Tonica: o corpo torna-se rígido;
2. Crônica: inicia-se movimentos com tremor de face, tronco e membros
3. De relaxamento: a vítima pode apresentar salivação e liberação involuntária de urina e fezes.
O tremor vai gradualmente diminuindo até o paciente fica completamente imóvel
Após alguns minutos, a consciência volta aos poucos, registrando-se, geralmente, um período curto de confusão mental, dor de cabeça e sonolência Frequentemente, há mordedura da língua.

### 12.3. O Que Fazer perante uma Crise

13.PARADA RESPIRATÓRIA (PR) E PARADA CARDIORRESPIRATÓRIA (PCR)

A parada respiratória (PR) é cessação repentina dos movimentos respiratórios e parada cardiorrespiratório (PCR) é cessação repentina dos batimentos cardíacos e dos movimentos respiratórios.
A circulação sanguínea deve ser restabelecida no máximo de 4 minutos, sob pena de se instalarem alterações irreversíveis nos tecidos, principalmente no cérebro, um dos mais Reanimação cardiopulmonar (RCP) é o conjunto de medidas utilizadas nas vítimas em PCR, com objetivo sensível de restabelecer a ventilação pulmonar e a circulação sanguínea à falta de oxigênio.

### 13.1. Causas de parada cardiopulmonar

- Obstrução de vias aéreas: inconsciência, trauma, corpo estranho
- Afogamento
- Overdose de drogas
- Choque elétrico
- Ataque cardíaco (infarto agudo do miocárdio)
- Trauma
- Grandes hemorragias
- Outros problemas clínicos (AVC)

### 13.2. Sinais de parada cardiopulmonar (PRC)

- Inconsciência (vítima não responde)
- Ausência de movimentos respiratórios
- Ausência de batimentos cardíacos

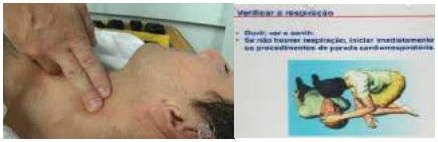
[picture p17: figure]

### 13.3. Passos para reanimação do PCR (parada cardiopulmonar)

1. Colocar a vítima deitada de costas sobre uma superfície firme (chão, ou maca)
2. Ajoelhar-se junto dela;
3. Verificar se está descordada
4. Tocar firmemente no ombro da vítima, chamando-a em voz alta e observar se há resposta. Se não houver, acionar ajuda especializada e iniciar reanimação cárdico pulmonar (RCP). Seguindoo passo da sequência do RCP: A, B, C, D.
A. Abrir as vias aéreas: inclinar a cabeça da vítima e elevação do queixo, paciente de trauma não se faz inclinação da cabeça, sob risco de lesão de medula; apenas se eleva o queixo. Ver- se há movimento do tórax e abdome. Ouvir –se há saída de ar durante a expiração. Sentir com sua bochecha se há fluxo de ar. Se não há respiração d\ê o próximo passo.

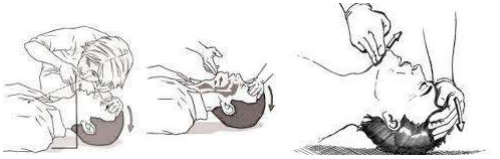
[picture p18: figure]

B. Respiração artificial boca a boca: manter as vias aéreas liberadas; pince o nariz da vítima (feche) usando polegar e o dedo indicador da mão que está na testa da vítima; inspira fundo e coloque seus lábios na boca da vítima, vendando-a completamente para impedir vazamento de ar; Sopre duas vezes lentamente dentro da boca da vítima. Manter a respiração de resgate ao ritmo de 12 insuflações por minuto.

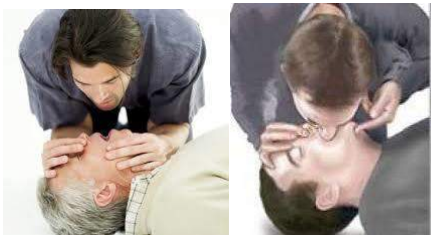
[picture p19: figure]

Existe no mercado protetores faciais para ventilação boca a boca que atua como barreira ao contato direto com secreções da vítima. É a respiração boca –a- máscara, também é chamado de máscaraantirreflexo. Ou de ressuscitação.

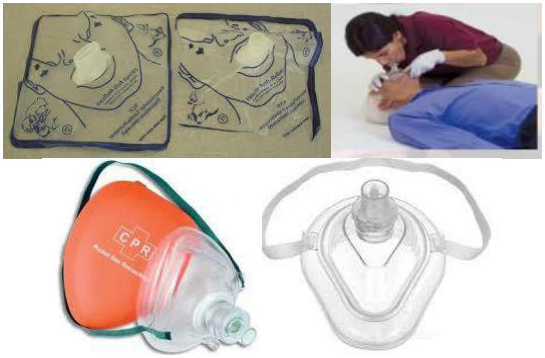
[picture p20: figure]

C. Circulação, paciente sem batimento do coração e sem pulso, iniciar massagem cardíaca externa ou compressão torácica. Localiza a margem inferior da caixa torácica, região do apêndice xifoide (ponta do osso esterno) e medir dois dedos acima. Este é o local da massagem cardíaca. Metade inferior do osso esterno, exatamente entre os mamilos. Evitar pega as costelas, podem causar fratura e lesão do pulmão.

Ressuscitação cardiopulmonar:

14.HEMORRAGIA

É a perda de sangue em decorrência de um ferimento, que pode ser externo ou interno. As causas da hemorragia são variadas e podem ir desde um corte com um caco de vidro ou uma faca, até um traumatismo com uma contusão que abriu e sangrou.

A hemorragia pode levar ao estado de choque e à morte. Por isso, ao perceber uma hemorragia é necessário estancar o sangue (no caso de uma hemorragia externa) e chamar a emergência imediatamente.

Sinais que levam a suspeitar de hemorragia interna:

- Mecanismo de lesão- os traumas contusos são as principais causas de hemorragia interna (quedas, chutes e explosões, acidentes de trânsito).
- Sinais de fratura de pelve e ossos longos (braço e fêmur) - o extravasamento de sangue nos tecidos moles ao redor da fratura pode provocar hemorragias severas.
- Dor e rigidez de abdome. Áreas extensa de contusão (equimose) na superfície do corpo.

- Ferida penetrante em crânio, tórax ou abdome

### 14.1. Controle de Hemorragia externa

Pressão direta sobe o ferimento

Controlam-se quase todos os casos de hemorragia externa pela pressão direta na ferida, o que faz interrupção do fluxo de sangue e favorece a formação de coágulo. Preferencialmente, utilize compressa de gazes ou improvise com pano limpo, pressionando firmemente durante 10 a 30 minutos.
Em seguida fixe a compressa com atadura ou bandagem ou outro tecido. Em sangramento profuso, não perca tempo em localizar compressa. Faça a pressão direta com a própria mão.
Elevação da área traumatizada e comprime pontos de pressão para parar hemorragia.
Quando se eleva uma extremidade de forma a deixá-la acima do nível do coração, a gravidade ajuda diminuir o fluxo de sangue. Aplique este método simultaneamente ao da pressão direta. Não o utilizem caso de fratura ou de objeto empalado na extremidade.
14.1.1. Os pontos de pressão

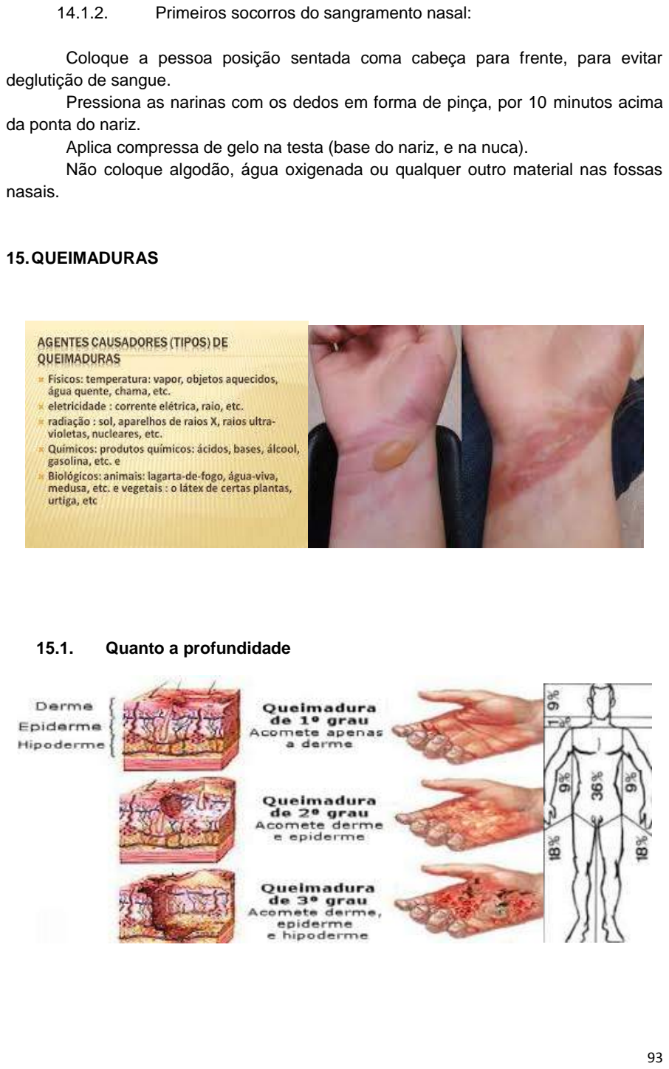
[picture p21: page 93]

14.1.2. Primeiros socorros do sangramento nasal:

Coloque a pessoa posição sentada coma cabeça para frente, para evitar deglutição de sangue.
Pressiona as narinas com os dedos em forma de pinça, por 10 minutos acima da ponta do nariz.
Aplica compressa de gelo na testa (base do nariz, e na nuca).
Não coloque algodão, água oxigenada ou qualquer outro material nas fossas nasais.

15.QUEIMADURAS

### 15.1. Quanto a profundidade

### 15.2. Como Lidar com Queimadura:

Lavar com água salgado morna e não água doce, se for queimadura por água viva.

16.DIARRÉIA

A Diarreia é uma evacuação de fezes líquidas que ocorrem com mais frequência do que o habitual e sem controle. ADiarreiaé uma das doenças mais comum no Brasil (perdendo apenas para infecção respiratória). Porém, a diarreia não costuma causar sérias complicações para a maioria dos pacientes. Entretanto, pode ser uma doença fatal para as crianças, especialmente aqueles que são desnutridas. Pode ser aguda e crônica.
Aguda- que dura algum dia e é mais frequente causada por uma infecção viral ou bacteriana, ou intoxicação alimentar.
Crônica- dura mais de duas semanas, e pode indicar deste a Síndrome do intestino irritado até condição mais graves tais
Como colite ulcerativa ou doença de Crohn.
Num acampamento: mais frequente é causado pelo vírus, bactérias ou parasitas; intoxicação alimentar, ou comida contaminada ou malconservadas, alergia alimentar ou água contaminadas.
Além da diarreia propriamente dita, há desconforte abdominal, cólica, plenitude (sensação de estofamento), excesso de flatulências, mal-estar generalizado, náuseas e vômitos. Isso leva à desidratação aguda. A vítima pode ficar com os olhos encovados, boca seca, turgir da pele diminuída, diminuição deurina, causa fraqueza e pode levar ao desmaio.

### 16.1. Como Evitar Infecção por Salmonela

17.MÉTODO DE TRANSPORTAR A VÍTIMA

### 17.1. Com somente um socorrista

Quando só tem um socorrista: pode arrastar a vítima, pelos pés, ou axilas, com um coberto, lona, carregas nas costas, no colo, ou apoiando quando este consegue caminhar

### 17.2. Com dois socorristas

### 17.3. Com Três ou mais socorristas

Deve-se ter cuidado com a cabeça, segurando-a para não causar um trauma cervical

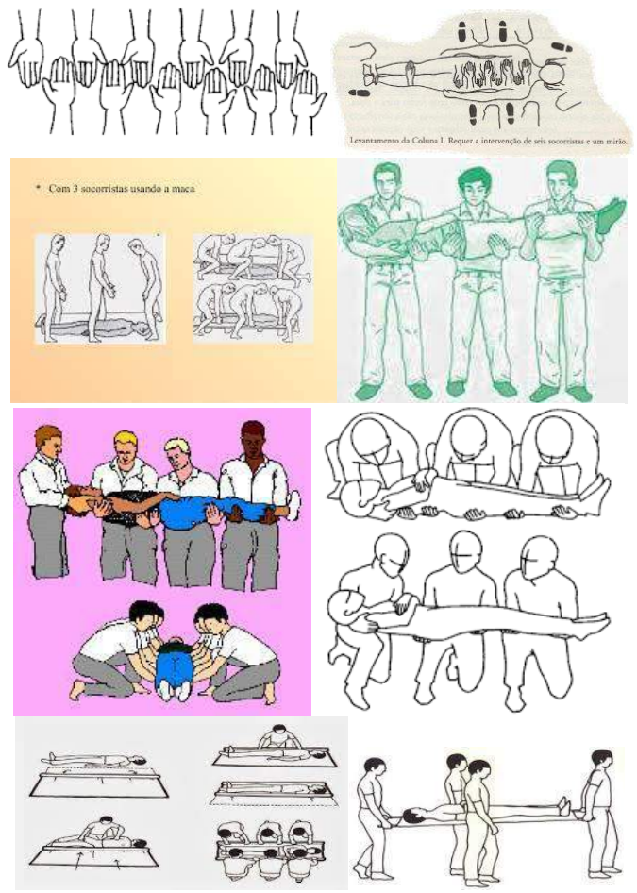
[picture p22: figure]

### 17.4. Improvisando macas

Transporte de lençol pelas pontas,cobertor ou lona. Lesão de coluna ,em superfície rígido.
Tipo de maca improvisado com materiais disponíveis:

18.TIPOS DE BANDAGENS

### 18.1. Bandagem Simples

Bandagem simples: A parte do corpo afetada é revestida com diversas voltas de ataduras, látex ou d e malha elástica. Estas bandagens são usadaspara sustentar curativos, para parar umahemorragia (https://fortissima.com.br/2014/02/17/hemorragia-sintomas-causas-e-tratamento-46524/) ou imobilizar uma articulação. Normalmente, são aplicadas de uma forma circular que se diferenciam entre bandagem em espiral e bandagem cruzada ou em oito

### 18.2. Bandagem em Espiral

Para a bandagem em espiral, podem ser feitas espirais simples. Comece com uma primeira volta em torno da extremidade (por exemplo no caso de braços, começar pelos pulsos), seguida por uma curva fechada lateralmente para sustentar a primeira. Em seguida, realize uma série de voltas em espiral, indo até a raiz do membro. Cada retorno deve cobrir dois terços da linha anterior. Finalize com duas voltas horizontais, dobre o fim da banda e prenda-o com um alfinete ou dois pedaços de esparadrapo.

### 18.3. Bandagem Cruzada ou em Oito

Para a bandagem cruzada ou em oito, comece com uma primeira curva à direita, em seguida, faça movimentos de oito, cruzando mais uma na vez frente e outra atrás. Repita esta manobra várias vezes até que a raiz do membro e prenda a extremidade da banda. Do antebraço. Essa bandagem pode ser feita a partir de um único

### 18.4. Bandagem Completa ou Tipoia

Este tipo de cobertura é um pedaço de tecido dobrado em forma de triângulo e amarrada por cima do ombro utilizado para dar suporte ao braço em caso de luxação do ombro ou fratura do antebraço. É contraindicada se o membro não estiver naturalmente na posição desejada (braço ao longo do 90 °). A mão deve ser posicionada ligeiramente mais elevada do que a do cotovelo.
Passe uma das extremidades do triângulo atrás do pescoço, no lado oposto ao braço lesionado. Traga a outra extremidade por cima do membro afetado, de modo que as duas extremidades possam ser amarradas logo acima da clavícula do lado lesionado.

### 18.5. Bandagem Completa ou Tipoia-Tubular

Bandagem tubular:frequentemente usado em lesões dos dedos após uma queimadura ou corte. Se cortar um comprimento de gaze com o dobro do comprimento do dedo que será coberto. A gaze é colocada na junta do dedo e leva uma segunda demão.

### 18.6. Bandagem Completa ou Tipoia- de gesso

Bandagem de gesso: Usada para imobilizar um membro fraturado. Após molhar os curativos, o médico os coloca sobre membro. Quando secos, formar uma camada rígida. Atualmente, o gesso está sendo substituído por faixas de resina, que são mais leves.

### 18.7. Bandagem Completa ou Tipoia- da cabeça

Bandagem da cabeça: Usada para segurar um curativo no ferimento ou para proteger o couro cabeludo. Um pedaço de tecido é dobrado em um triângulo. Como se fosse uma badana, (https://fortissima.com.br/2013/11/27/aprenda-ondular-seus-cabelos-com-uma-bandana-28003/) o lado mais comprido é colocado sobre a testa, na altura das sobrancelhas. Finalmente, as extremidades são atadas na nuca.

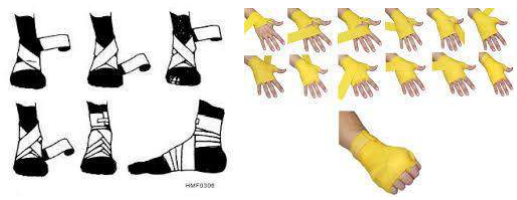
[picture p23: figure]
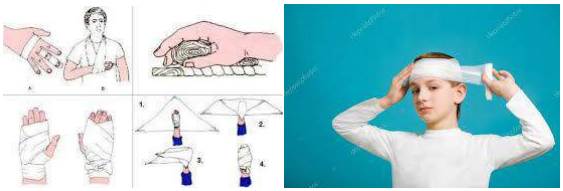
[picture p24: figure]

19.MEDIDADES DE SEGURANÇA NAS ATIVIDADES ESCOTEIRAS

### 19.1. Rapel

O Rapel é um esporte que atrai pessoas aventureiras e que gostam de estar em contato com a natureza. É uma prática que além de trazer prazer ao seu praticante também funciona como exercício físico, melhorando a resistência e a força do esportista.
Por outro lado, praticar Rapel é algo que demanda certos cuidados com a segurança. É preciso, acima de tudo, ter domínio do equipamento que se está usando. Saiba como montar uma cadeira de rapel
Um dos principais aparados do praticante de Rapel é a cadeirinha. É extremamente importante que o usuário coloque a Cadeirinha corretamente e afivele todos os outros equipamentos de maneira correta e fica. O ponto de ancoragem deve estar próximo para ser manuseado de forma fácil e rápida.
Além disso, o esportista de Rapel deve prender bem seu freio à cadeirinha e à corda.
Da mesma forma, na hora de comprar os equipamentos, garanta que a Cadeirinha, corda, freio 8, fita e outros tenham sido fabricadas por empresas confiáveis. Uma ótima sugestão é pesquisar em fóruns por opiniões de outros usuários. As alças laterais, também conhecidas como Gear Loops, não devem ser usadas para suportar o peso do alpinista. Elas são indicadas para carregar outros itens. Outras dicas:
- Nunca coloque seu pé sobre a corda
- Procure por um capacete confortável. Ele diminui muito os riscos em uma descida
- Pratique os nós da corda apenas com uma mão. A prática irá facilitar muito na hora do Rapel
- Em caso de cabelos compridos, prenda-os antes de iniciar
- No início, procure por descidas fáceis e vá aumentando o nível gradativamente.

19.1.1. Dicas gerais
- Estar em boas condições físicas e mentais.
- Saber o que vai fazer.
- Planejar antecipadamente.
- Possuir um equipamento adequado. Obs.: Os equipamentos referentes vão desde as roupas até os aparelhos técnicos.
- Saber como se equipar.
- Levar só o necessário.
- Nunca estar sozinho.
- Avisar outras pessoas para onde você está indo.
- Observar as condições meteorológicas.
- Respeitar seus limites.
- Respeitar os limites dos parceiros.
- Respeitar os limites da natureza.
- Estudar antes a região predestinada ao esporte.
- Preservar o máximo o meio ambiente.
- Ter uma condução adequada.
- Estar sempre acompanhado de alguém que tenha algum tipo de experiência no esporte.
- Estar bem alimentado.

Não se aventurar com empresas que não possuem experiência comprovada

19.1.2. Dicas para a prática do rapel
- Antes de sair para a prática do rapel confira um a um todo o material. Mesmo que você saiba que está tudo OK. É sempre bom estar prevenido.
- Dê preferência aos equipamentos que tenham os selos de certificação (UIAA, CE, EN) e que tenham a sua capacidade de peso suportada gravada no próprio aparelho. Estes selos garantem que todos são testados e aprovados.
- Leia o manual do produto que você comprar. Confira os pesos suportados, mínimos e máximos. Verifique cada detalhe do produto.
- Sempre cheque duplamente o seu sistema de rapel
- Confira seus nós, a fivela da cadeirinha e o mosquetão principal.
- Inspecione seu equipamento e troque-o quando necessário.
- Confira se há alguém fazendo sua segurança.
- Leia todos os avisos de atenção - eles podem salvar sua vida.

- Equipamento fixo é duvidoso - sempre utilize um backup.
- Olho atento às condições do tempo.
- Sempre tenha certeza de estar conectado ao sistema de segurança (bases, fitas, pinos, etc.) com backup e redundância.
- Sempre até um nó na (s) ponta (s) da corda quando for rapelar e não confie em marcas de meio feitas de fita adesiva.
- Fitas e cordas de abandono podem estar abandonados há muito tempo... o suficiente para não estarem mais confiáveis.
- Cuidado com pedras e blocos soltos, eles existem.
- Nunca se exponha perto da beirada sem estar encordado/ancorado.
- Luvas:

No Rapel o uso de luvas é muito comum. A maioria dos praticantes não tem conhecimento das formas de passada de corda no freio (lenta, comum e rápida) e acabam por preferir utilizar a luva para não queimar as mãos.

19.1.3. Cuidados que devem ser tomados:

A prática de rapel deve ser executada em grupo, pois um integrante é sempre responsável pela vida de outro. Toda descida deve ter no mínimo três participantes:
- O que aborda: É o responsável por colocar o praticante na corda, conferir se seu equipamento está correto e orientá-lo no momento da abordagem.
- O que desce: É o praticante atual, ou seja, quem vai fazer a descida.
- O que faz a segurança: É a pessoa que vai estar lá em baixo, segurando a corda, atento a qualquer vacilo que o que desce possa dar.

### 19.2. Fogo e Fogueiras

19.2.1. Fogueiras

Os principais cuidados de segurança, para uso de uma fogueira, são:

- Limpando o chão: antes de acender uma fogueira, todo o capim, folhas secas, mato, etc., deve ser removido ao redor do local escolhido, evitando que o fogo se propague ao redor. Muitos incêndios em matas foram causados por acampastes que não observaram as regras de segurança.
- Entorno: o fogo deve encontrar-se longe de barracas e lugares onde pessoas transitam; o espaço da cozinha deve permitir o livre e seguro movimento dos cozinheiros, e a área da fogueira protegida com pedras que a rodeiem ou montada em um buraco.
- Combustível: não se utiliza, nunca, combustível inflamável para acender o fogo.
Os jovens devem ser orientados para usar “iscas” sólidas, não explosivas, como pastilhas de álcool-gel, bastões encerados, ou os “acendalhas” tradicionalmente
usados no Escotismo. É importante assegurar-se de que as patrulhas não dispõem de álcool ou outro combustível para facilitar o acendimento.
- Caso seja necessário fazer o fogo sobre a grama, será conveniente cortar com a pá o terreno e retirar uma camada de grama com solo, de no mínimo 12 cm; guardar em um local úmido, pois ele será utilizado para cobrir o local ao final da atividade.
- Apagando o fogo: deve-se verificar que a fogueira esteja bem apagada antes de abandonar o local. O fogo deverá ser apagado com água e terra, e deve se pisar bastante em cima dele para que não fique nenhuma fagulha acesa que possa mais tarde iniciar um incêndio. Finalmente, repõem-se a camada de terra com vegetação que estava ali.

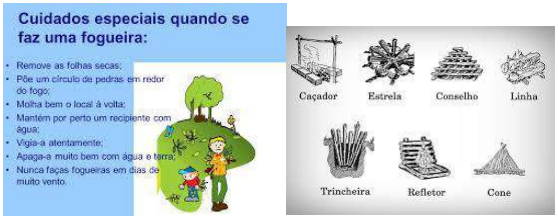
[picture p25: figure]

Evitar queimadura das mãos usa luvas e pano de prato na hora da cozinha.

19.2.2. Regras de segurança ao se fazer fogo e fogueiras

Das atividades escoteiras ao ar livre - a maioria delas - envolvem fogo e/ou fogueira, seja ela para preparar ou aquecer algum alimento ou realizar um Fogo de Conselho.
Esta atividade, além de prazerosa, leva o jovem a avançar seu limite e vivência além do seu cotidiano, já que não está presente em seu dia a dia. Contudo, e isto deve ser motivo de atenção, assim como o fogo ou uma fogueira pode causar momentos inesquecíveis, pode também causar acidentes, e isto deve e pode ser evitado.
Para decidir-se sobre uso de fogo ou confecção de uma fogueira, deve-se preliminarmente considerar:
a) A disponibilidade de equipamento próprio, como fogareiro, ou a necessidade de construir fogão ou fogueira;
b) A finalidade, que vai indicar o uso de equipamento ou tamanho da fogueira e tipo de lenha desejável;
c) O local onde será confeccionada, se indica riscos e consequentes cuidados;
d) Devem ser certificados pelo INMETRO e estar dentro da validade
19.2.3. Regras de segurança para uso de fogareiro a gás
- Manter o fogareiro protegido do vento, evitando apagamento da chama e vazamento de gás, que podem provocar intoxicações ou incêndios.
- Nenhum botijão deve ser exposto à temperatura superior a 50°C, razão pela qual não se conectam acessórios como fogareiros, lampiões e outros tipos de queimadores diretamente na válvula do botijão, pois isso pode derreter o plugue-fusível e causar incêndio.
- O botijão deve estar em local arejado, distante do fogo pelo mínimo a 80 cm, e a mangueira e o regulador que a mangueira não fique encostada no fogareiro, evitando que ela derreta e cause acidente.

- O botijão nunca pode ser armazenado em compartimentos fechados, como barracas, caixas de patrulha, armários, etc. Deve ser transportado em pé e jamais pode ser rolado. Alguns estados têm legislação específica sobre transporte de botijão.
- A compra do botijão deve ser feita em empresa autorizada, com a marca estampada em relevo no mesmo, lacre e etiqueta, garantindo que passou por teste. Jamais, em hipótese alguma, admite-se que se faça recarga de gás com aparelhos improvisados, em companhia ou terceiros não autorizados.
- Quando a alimentação dos queimadores do fogão estiver insuficiente, provavelmente o gás acabou. Não se deve tentar forçar a saída de gás ou aquecer o botijão. Nunca se deve virar ou deitar o botijão, pois se ainda existir algum resíduo de gás, ele poderá escoar na fase líquida, o que anula a função do regulador de pressão, podendo provocar graves acidentes, assim como entupir com impurezas o regulador, a mangueira e os queimadores.

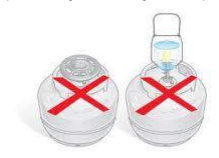
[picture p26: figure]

- Antes de trocar o botijão deve-se assegurar de que todos os botões dos queimadores do fogão estão desligados, nunca efetuando a troca próximo de chamas, brasas, faíscas ou qualquer outra fonte de calor.
- O lacre deve ser retirado levantando a própria aba do anel externo e girando-a no sentido anti-horário até o disco central sair completamente. Após retirado do regulador do botijão vazio ele deve ser encaixado e rosqueado sobre a válvula do botijão cheio, fazendo o aperto final apenas com as mãos e jamais usando ferramenta.
- Em nenhuma hipótese pode-se usar fogareiro dentro de barracas, bem como não se deve mantê-lo em local onde se dorme, mesmo que apagado.

- Para que os fogareiros possam prestar bons serviços, é indispensável que sejam mantidos limpos e em ordem. As mesmas regras e orientações servem para a utilização de lampiões a gás.

### 19.3. Instrumento de Corte

19.3.1. Facão
19.3.2. Machadinha

A machadinha é um machado de pequenas dimensões, que é adequada para cortar a lenha que precisamos para a cozinha. O facão é indicado para abrir uma trilha no mato, que fechou por falta de uso; limpar de pequenos arbustos o local que você vai montar seu acampamento; e realizar trabalhos leves, substituindo a machadinha, como, por exemplo, fazer entalhes para encaixar peças de pioneiras, fazer ponta em vara de pequeno diâmetro, etc.

Para usá-los, siga estas regras de segurança:

- Terminado o trabalho, limpe a ferramenta e passe um óleo ou graxa para evitar que enferruje.
- Trabalhe afastado dos demais, de preferência a uns 3m de distância da pessoa mais próxima.
- Trabalhe de preferência no "canto do lenhador", ou seja, aquela área cercada onde apenas a pessoa da patrulha encarregada de cortar lenha deve entrar. Neste canto também há um tronco seco e grosso, também chamado de cepo, que serve para apoiar o que está sendo cortado.
- Quando golpear, faça-o sempre para fora de seu corpo. Observe que se o facão ou machadinha errar o alvo, não atinja nenhuma parte de seu corpo.

- Não fique andando de um lado para o outro com a ferramenta na mão.
- Não use a machadinha como martelo ou marreta.
- Preste muita atenção quando passar a ferramenta para outra pessoa. Tenha certeza que ela está firmemente segurando a ferramenta.
19.3.3. Transporte dos instrumentos

### 19.4. Esquema de Vacinação:

Febre Amarela é necessário para quem vai viajar para cidade e ou países epidemiológicos de risco que exigem comprovante nacional ou internacional,
Para efeito de emissão do Certificado Internacional de vacinação ou Profilaxia (CIVP): esse certificado só será válido a partir dos 10.º dias após a aplicação da 1ª dose da vacina (primovacinação)
Atualmente não precisa fazer reforço, basta uma dose para jovens e adultos já considera imunizado.
Antitetânico: d’ (duplabacteriana uso adulto) énecessário após 7 anos de idade fazer reforço a cada 10 anos. Considerando que já esteja com esquema de vacinação completa

HepatiteB (recombina-te) 3 doses.
Tríplice viral (VTV ou SCR) Vacina contra Sarampo, Rubéola e Caxumba
Tetra viral (Sarampo, caxumba, Rubéola e Varicela) Pessoas com 5 anos até 29 anos 11meses e 29 dias de idade, é de 2 doses da Tríplice viral (VTV) com intervalo mínimo de 30 dias entre elas.
Considerar vacinada a pessoa que comprovar ter recebido 2 doses de VTV, ou 2 doses de SCRC, ou 1 dose VTV e 1 dose SCRV
Pessoas com 30 anos até 49 anos 11 meses e 29 dias de idade: administrar 1 dose da Tríplice Viral (VTV). Considerar vacinada a pessoa que comprovar ter recebido 1 dose de VTV
Considerar vacinada a pessoa que comprovar ter recebido 2 doses de VTV; ou 2 doses de SCRV, ou 1 dose de VTV e 1 dose de SCRV.
HPV- para meninas de 9 anos até 14 anos 11 meses e 29 dias. 2 doses com intervalo de 6 meses.
Para meninos de 11 anos até 14 anos 11 meses e 29 dias. 2 doses com intervalos de 6 meses.
Meningocócica C adolescentes de 12 anos até 13 anos 11 meses e 29 dias
Não vacinados administrar dose única.
- Esquema não completos: administrar 1 reforço.
- Com histórico de 3 doses de meninosC: administrar 1 reforço
- Com histórico vacinal de 4 doses: Não vacinar

A importância de todas essas vacinas é prevenir as doenças, atividade escoteira geralmente é em grupo com muitas pessoas de outras cidades ou outros países.

20.REFERÊNCIAS BIBLIOGRÁFICAS

Livro: Acampar e Explorar, tudo o que é necessário saber para realizar boas atividades ao ar livre. União dos Escoteiros doe Brasil.

Como fazer um Curativo: www.tuasaúde.com

Curso e cotista ramoescoteiro Nível Básico, Gestão de Adultos (apostila do cursam-te)

Emergência Atendimento Inicial. Suas mãos podem salvar uma vida.

Guia da aventura escoteira Pista e Trilha, Rumo e Travessia.

Manual do e cotista Ramos Escoteiro

Guias da Aventura Escoteira, Pista Trilha e Rumo e Travessia.

Padrão de atividade escoteira da União Escoteira do Brasil

Pesquisa pelo Internet, como fazer um Curativo,WWW.tuasaúde.com

Socorros em atividades físicas, Manual da escola de enfermagem do DF.

Google, sobre pesquisa e as imagens e fotos e figurinhas.

Site da secretaria de saúde do estado do Paraná.

Site do Ministério de saúde do Brasil.

YOutubesobre reanimação cardiopulmonar.

Livro: Trauma atendimento pré-hospitalar, autora Beatriz F.Monteiro Oliveira.e outros.

Site de alguns grupos escoteiros que tem matérias sobre escotismo.

21.Anexos

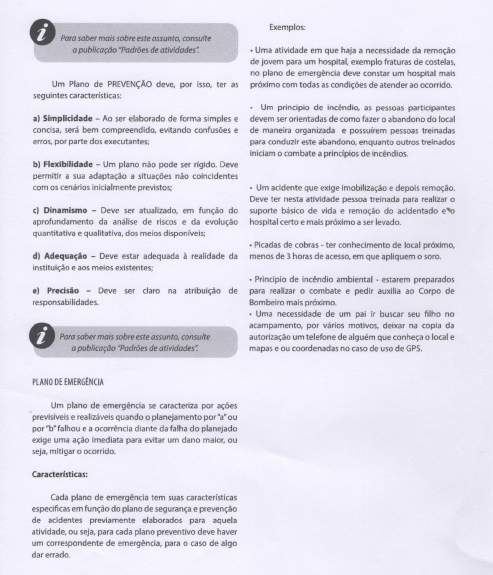
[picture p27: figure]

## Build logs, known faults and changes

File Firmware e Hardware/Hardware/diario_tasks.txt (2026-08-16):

medir distancia dos servos do modelo até a carga?
baterias, quais capacidades e tensao, caracteristicas de descarga, tensao de corte, datasheet ou generalizar dentro de algum seguro?

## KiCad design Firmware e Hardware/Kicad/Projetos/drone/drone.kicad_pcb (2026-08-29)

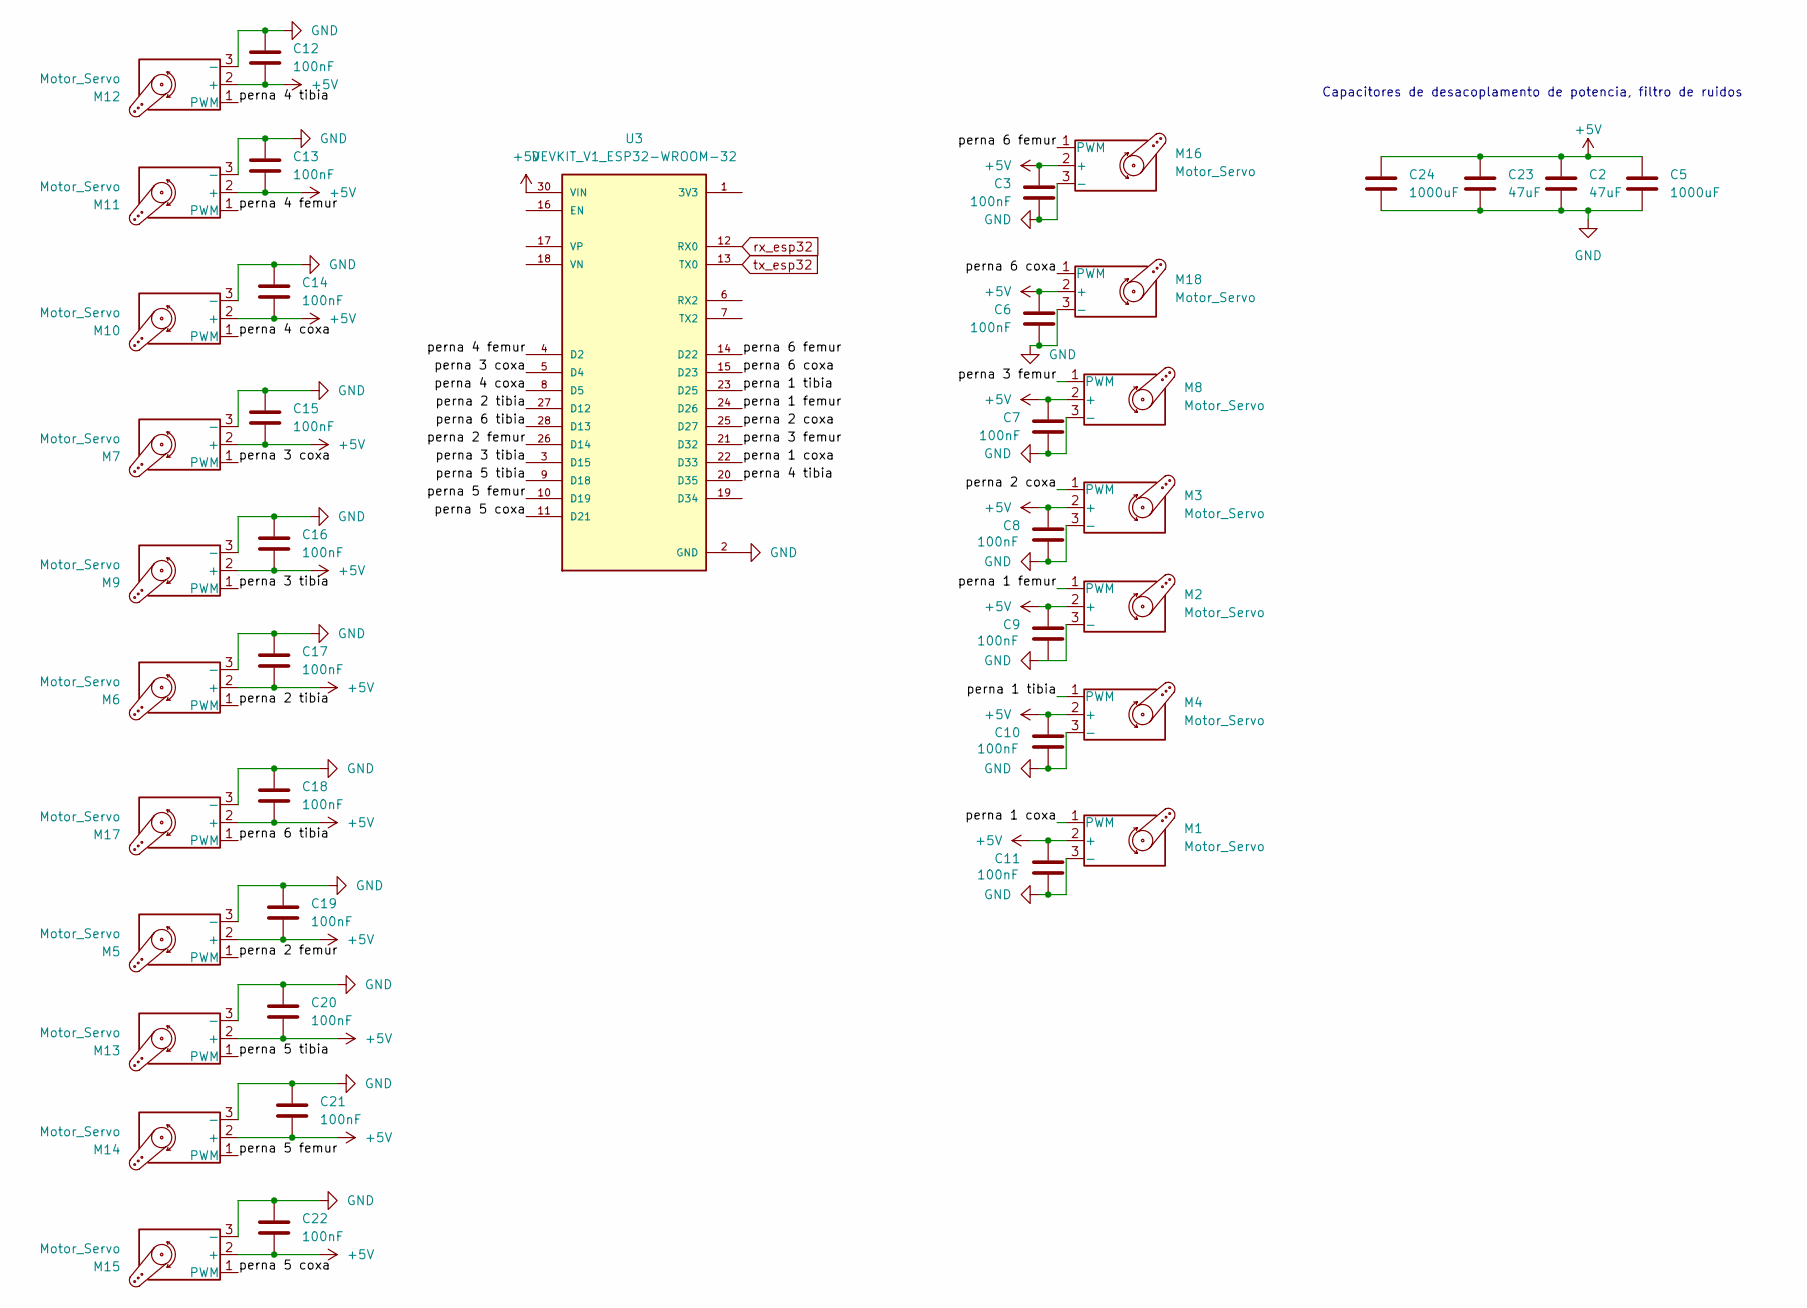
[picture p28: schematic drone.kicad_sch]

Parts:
C2, C23: 47uF; C_Disc_D7.0mm_W2.5mm_P5.00mm
C3, C6, C7, C8, C9, C10, C11, C12, C13, C14, C15, C16, C17, C18, C19, C20, C21, C22: 100nF; C_Disc_D7.0mm_W2.5mm_P5.00mm
C5, C24: 1000uF; C_Disc_D7.0mm_W2.5mm_P5.00mm
M1, M2, M3, M4, M5, M6, M7, M8, M9, M10, M11, M12, M13, M14, M15, M16, M17, M18: Motor_Servo; PinHeader_1x03_P2.54mm_Vertical
U3: DEVKIT_V1_ESP32-WROOM-32; MODULE_DEVKIT_V1_ESP32-WROOM-32

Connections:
+5V: C2.1, C3.1, C5.1, C6.1, C7.1, C8.1, C9.1, C10.1, C11.1, C12.2, C13.2, C14.2, C15.2, C16.2, C17.2, C18.2, C19.2, C20.2, C21.2, C22.2, C23.1, C24.1, M1.2 (+), M2.2 (+), M3.2 (+), M4.2 (+), M5.2 (+), M6.2 (+), M7.2 (+), M8.2 (+), M9.2 (+), M10.2 (+), M11.2 (+), M12.2 (+), M13.2 (+), M14.2 (+), M15.2 (+), M16.2 (+), M17.2 (+), M18.2 (+), U3.30 (VIN); also elsewhere on the board
/Raiz/perna 1 coxa: M1.1 (PWM), U3.22 (D33)
/Raiz/perna 1 femur: M2.1 (PWM), U3.24 (D26)
/Raiz/perna 1 tibia: M4.1 (PWM), U3.23 (D25)
/Raiz/perna 2 coxa: M3.1 (PWM), U3.25 (D27)
/Raiz/perna 2 femur: M5.1 (PWM), U3.26 (D14)
/Raiz/perna 2 tibia: M6.1 (PWM), U3.27 (D12)
/Raiz/perna 3 coxa: M7.1 (PWM), U3.5 (D4)
/Raiz/perna 3 femur: M8.1 (PWM), U3.21 (D32)
/Raiz/perna 3 tibia: M9.1 (PWM), U3.3 (D15)
/Raiz/perna 4 coxa: M10.1 (PWM), U3.8 (D5)
/Raiz/perna 4 femur: M11.1 (PWM), U3.4 (D2)
/Raiz/perna 4 tibia: M12.1 (PWM), U3.20 (D35)
/Raiz/perna 5 coxa: M15.1 (PWM), U3.11 (D21)
/Raiz/perna 5 femur: M14.1 (PWM), U3.10 (D19)
/Raiz/perna 5 tibia: M13.1 (PWM), U3.9 (D18)
/Raiz/perna 6 coxa: M18.1 (PWM), U3.15 (D23)
/Raiz/perna 6 femur: M16.1 (PWM), U3.14 (D22)
/Raiz/perna 6 tibia: M17.1 (PWM), U3.28 (D13)
GND: C2.2, C3.2, C5.2, C6.2, C7.2, C8.2, C10.2, C11.2, C12.1, C13.1, C14.1, C15.1, C16.1, C17.1, C18.1, C19.1, C20.1, C21.1, C22.1, C23.2, C24.2, M1.3 (-), M2.3 (-), M3.3 (-), M4.3 (-), M5.3 (-), M6.3 (-), M7.3 (-), M8.3 (-), M9.3 (-), M10.3 (-), M11.3 (-), M12.3 (-), M13.3 (-), M14.3 (-), M15.3 (-), M16.3 (-), M17.3 (-), M18.3 (-), U3.2 (GND), U3.29 (GND); also elsewhere on the board
rx_esp32: U3.12 (RX0); also elsewhere on the board
tx_esp32: U3.13 (TX0); also elsewhere on the board

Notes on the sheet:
Capacitores de desacoplamento de potencia, filtro de ruidos

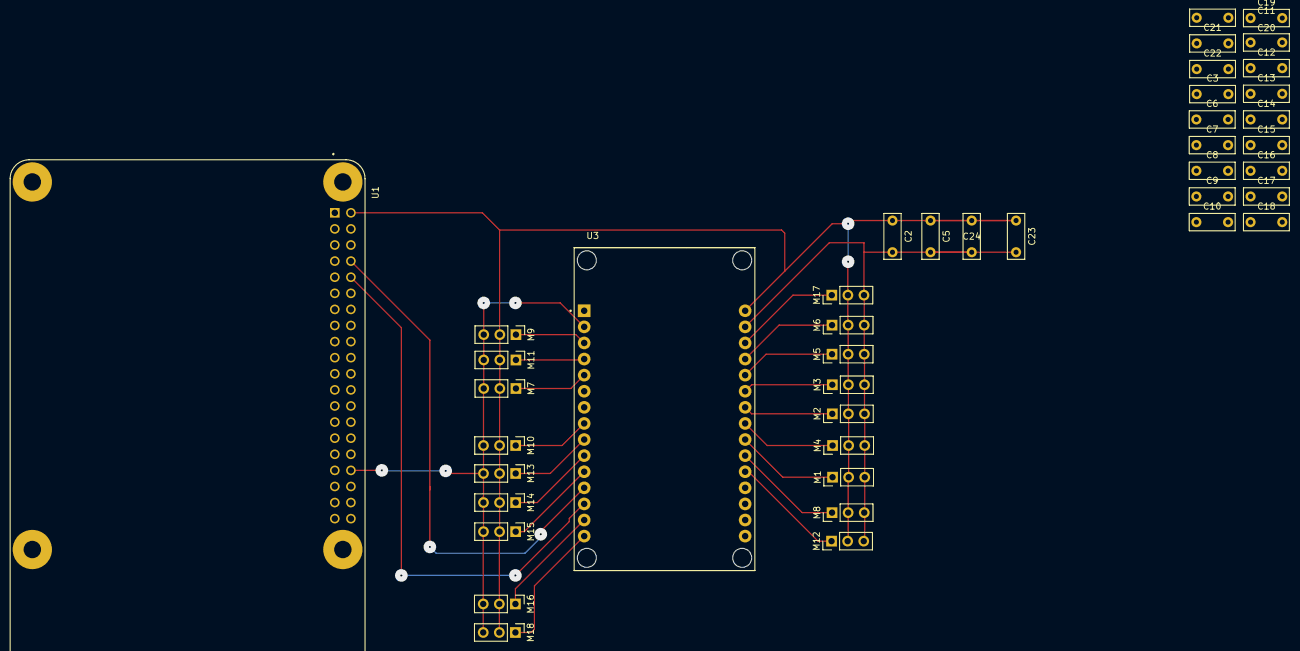
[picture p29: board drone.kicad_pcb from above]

Board: 2 copper layers, 42 parts (0 on the bottom side), 24 nets.

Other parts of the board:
U1: SC0195_9_; MODULE_SRASPBERRY_PI_4_MODEL_B_

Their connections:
3V3: U1.1 (3V3), U1.17 (3V3)
+5V: U1.2 (5V0), U1.4 (5V0); also elsewhere on the board
GND: U1.6 (GND), U1.9 (GND), U1.14 (GND), U1.20 (GND), U1.25 (GND), U1.30 (GND), U1.34 (GND), U1.39 (GND); also elsewhere on the board
SHIELD: U1.S1 (SHIELD), U1.S2 (SHIELD), U1.S3 (SHIELD), U1.S4 (SHIELD)
rx_esp32: U1.8 (TXD0/GPIO14); also elsewhere on the board
tx_esp32: U1.10 (RXD0/GPIO15); also elsewhere on the board

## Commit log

2026-05-29 Expand README with study areas and applications
    Added sections on areas of study and application related to embedded systems, communication networks, robotics, computer vision, and power electronics.
2026-06-15 model 4 B
    [aracnobot.kicad_pcb, aracnobot.kicad_sch]
2026-06-15 Pasta de datasheet
2026-08-07 datasheets atualizacao 7 de agosto
    [DEVKIT_V1_ESP32-WROOM-32.step]
2026-08-08 Kicad atualaizao footprint e schematico
    [aracnobot.kicad_pcb, aracnobot.kicad_sch]
2026-08-12 tabela pinagem esp32 - hexapod
2026-08-20 kicad atualizacao, servo motores
    [aracnobot.kicad_sch]
2026-08-24 kicad atualizacao
    [aracnobot.kicad_pcb, aracnobot.kicad_sch, drone.kicad_pcb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]
2026-08-25 roteamento, servos - esp32
    [drone.kicad_pcb]
2026-08-26 remove arquivos impedindo colaboração no kicad
2026-08-29 capacitores de desacoplamento no kicad
    [drone.kicad_pcb, drone.kicad_sch, raspberry.kicad_sch]
2026-09-01 circuito de regulagem da bateria
2026-09-25 Atualização de componetes disponiveis
2026-10-02 simulacao do controle de corrente do robo
